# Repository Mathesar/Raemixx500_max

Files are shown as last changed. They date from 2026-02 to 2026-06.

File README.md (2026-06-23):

# Rämixx500_MAX

Rämixx500_MAX is an enhanced version of Sukkoperra's [Rämixx500](https://github.com/SukkoPera/Raemixx500), an Open Hardware remake of the Commodore Amiga 500+ mainboard, revision 8A.1.

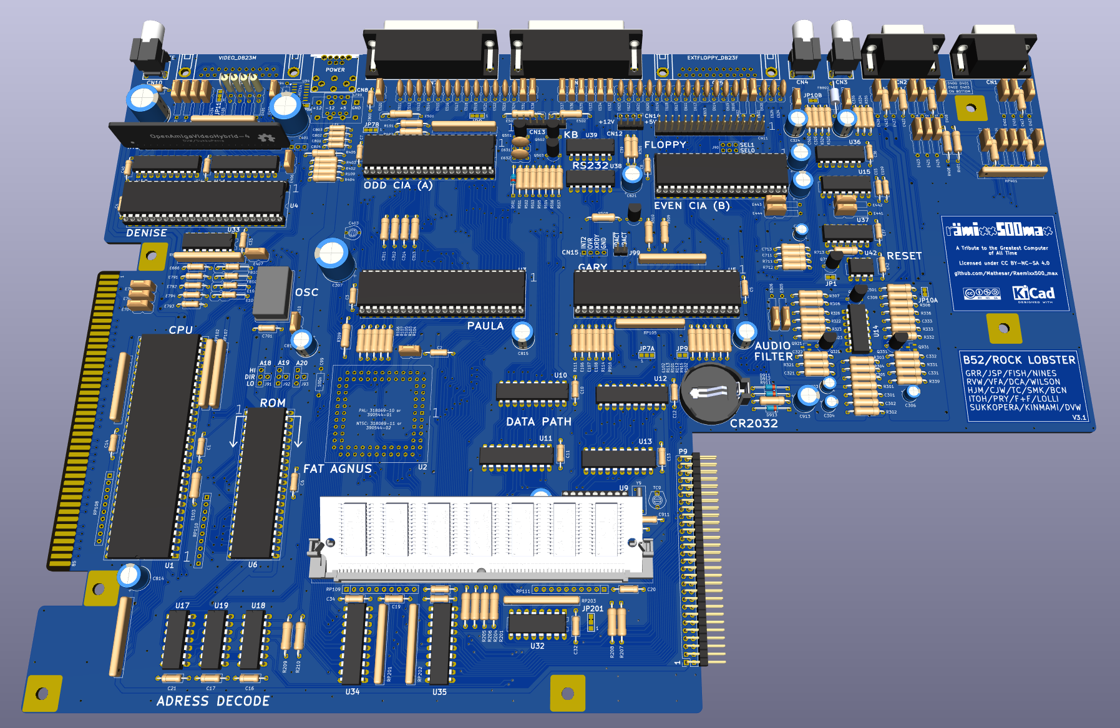
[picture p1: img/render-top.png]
board


## Features
The main feature of the Rämixx500_MAX compared to the original Rämixx500 is more RAM in the form of a 72pins 4Meg SIMM module that gives the Rämixx500_MAX 2Meg CHIP + 1.5Meg SLOW ram. Good working SIMM modules are much easier to source and more reliable than the DIP chips that were originally used in the A500+.

3.5 Megabytes of RAM is the maximum amount an A500+ can use without attaching an accelerator, hence the name Rämixx500_**MAX**.

All the new features of the Rämixx500_MAX are:

* **3.5 Megabytes of RAM**: Using a 72pin SIMM that is at least 4Meg in size.
* **Improved ESD Protection for the Joystick Ports**: The Rämixx500_MAX protects just the lines that go into the sensitive CIA and Paula chips but these lines are more rigorously protected by placing the ESD diodes right at the connectors.
* **Improved Hard Disk LED support**: This version accepts both active high and active low harddisk activity signals. Note that the active low harddisk activity LED input is only compatible with 5V devices. The active high harddisk activity LED input is compatible with both 3.3V and 5V devices.
* **Even more Accurate Dimensions**: The floppy port should fit slightly better. (It already was very, very close in the original Rämixx500 though)
* **Less jumpers**: With the SIMM module, one always has max RAM in all banks, no need to jump around with JP2, JP3 and JP4 anymore.

## Ordering parts and building (important)
Included with the gerbers is a BOM that contains most of the needed parts. Mouser part numbers are also included. 

The BOM and schematics reflect how I built my version. There are some options like buffered sync outputs and extra pullups that I did not use. If one wants these options then they will have to order the additional parts as well. 

Some more remarks regarding how I built my Rämixx500_MAX:

* I did not use sockets for all parts. I only used sockets for the second-hand / rare parts. All the standard logic IC's for example are not socketed. 
* For the 68000 the BOM specifies a high quality "machined" socket. This is done for reliable connection to a socketed accelerator. 
* The other sockets are standard "wiped" sockets. If one is planning to use, for example, an [A500_SD_PLUS](https://github.com/Mathesar/a500-sd-plus-controller) or a RGB2HDMI it is recommended to change the respective sockets (CIA / Denise) to machined sockets as well. This is because I have noticed that modern production wiped sockets get very loose if you insert something other that an IC in them.
* I have populated RP105, RP106 and RP107. This is unlike the original A500+ but these pullups help EPROM compatibility.
* In the BOM I have replaced the MC1488 and MC1489 with the functionally identical SN75C188N and SN75C189N.  
* In the BOM I have replaced the 74F139 with the CD74ACT139E.
* I did not populate the trapdoor connector P9 (not needed anymore).

Like said, the BOM will give you most of the parts needed. The missing parts are:

* **68000** (socket included in BOM)
* **Agnus** (socket included in BOM, only certain versions supported!)
* **Paula** (socket included in BOM)
* **Gary** (socket included in BOM)
* **Denise** (socket included in BOM)
* **2 CIA's** (socket included in BOM)
* **RTC U9** (socket included in BOM)
* **Trimmer capacitor TC-9** (for RTC)
* **Main oscillator X1** (PAL or NTSC)
* **Floppy DSUB connector**
* **Video DSUB connector**
* **Power connector**
* **SIMM module**
* **VIDIOT**

Any SIMM that is 4Meg or larger is supported. EDO and/or parity RAM is also supported.
There is one caveat though when using double-sided SIMM's. As the RTC chip is normally sitting in a socket it might interfere with the memory chips on the bottom of some SIMMs. All double-sided SIMMs I tested fitted but "your mileage may vary".
Also, The SIMM socket sticks out higher than the original DIP RAM chips. This can have implications for some accelerators or other add-ons that sit in the CPU socket. If one plans to use additional add-ons, please review carefully whether these will physically fit on the Rämixx500_MAX. Also see my remarks regarding IC sockets.

For the vidiot, one can use the [OpenAmigaVideoHybrid-04](https://github.com/Mathesar/OpenAmigaVideoHybrid-04) that I have also forked from Sukkoperra.

For further information I highly recommend reading [Sukkopera's wiki here](https://github.com/SukkoPera/Raemixx500/wiki/Assembly-and-Installation). Especially for important information regarding the correct Agnus version.

## Extras
I put my Rämixx500_MAX in a new case from [a1200.net](https://www.a1200.net/). 
For that I also needed a floppy drive so I modded a Sony MFP920 PC drive.
In the [extras](https://github.com/Mathesar/Raemixx500_max/tree/master/extras) folder in this repo one can find the FreeCad and STEP files for an eject button for this drive. I have also created an adapter that converts the Chinon eject button that comes with the a1200.net case to the Sony MFP920 drive. The Chinon eject button itself needs to be trimmed a bit on the back and then glued over the adapter.

## Releases
If one wants to get this board produced, one is recommended to get the latest release rather than the current git version, as the latter might be under development and is not guaranteed to be working.
The latest release also contains the BOM with Mouser part numbers and an interactive HTML BOM which is very helpful when populating the boards.

## Disclaimer
I have personally built and tested V3 of the Rämixx500_MAX. The current release is V3.1 that fixes some (very) minor issues. However, I have not built or tested V3.1 myself. So, build at your own risk.

## License
The Rämixx500_MAX inherits the license of the The Rämixx500 by SukkoPera as quoted below:

> The Rämixx500 documentation, including the design itself, is copyright &copy; SukkoPera 2019-2021 and is licensed under the [Creative Commons Attribution-NonCommercial-ShareAlike 4.0 International License](https://creativecommons.org/licenses/by-nc-sa/4.0/).
> 
> This documentation is distributed *as is* and WITHOUT ANY EXPRESS OR IMPLIED WARRANTIES whatsoever with respect to its functionality, operability or use, including, without limitation, any implied warranties OF MERCHANTABILITY, SATISFACTORY QUALITY, FITNESS FOR A PARTICULAR PURPOSE or infringement. We expressly disclaim any liability whatsoever for any direct, indirect, consequential, incidental or special damages, including, without limitation, lost revenues, lost profits, losses resulting from business interruption or loss of data, regardless of the form of action or legal theory under which the liability may be asserted, even if advised of the possibility or likelihood of such damages.
> 
> This said, I would like this project to progress further. **If anyone would like to do major work on it but is discouraged to do so by the impossibility to exploit the work commercially, please get in touch with me**, I will grant you a private license which will allow you to do that.

## Thanks
- Commodore, for making the coolest machine ever.
- [SukkoPera](https://github.com/SukkoPera) for creating the amazing Rämixx500 and making it open source. Without him this would have never been possible.
- [PeteAU](https://eab.abime.net/member.php?u=58900) for designing an A500 trapdoor RAM expansion and gary adapter. His design inspired me to give the Rämixx500_MAX some additional RAM.

## Pictures

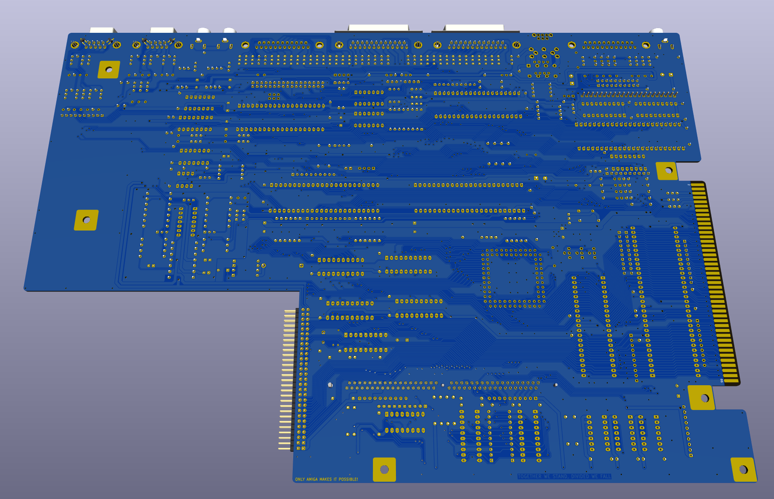
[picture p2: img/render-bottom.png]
bottom render


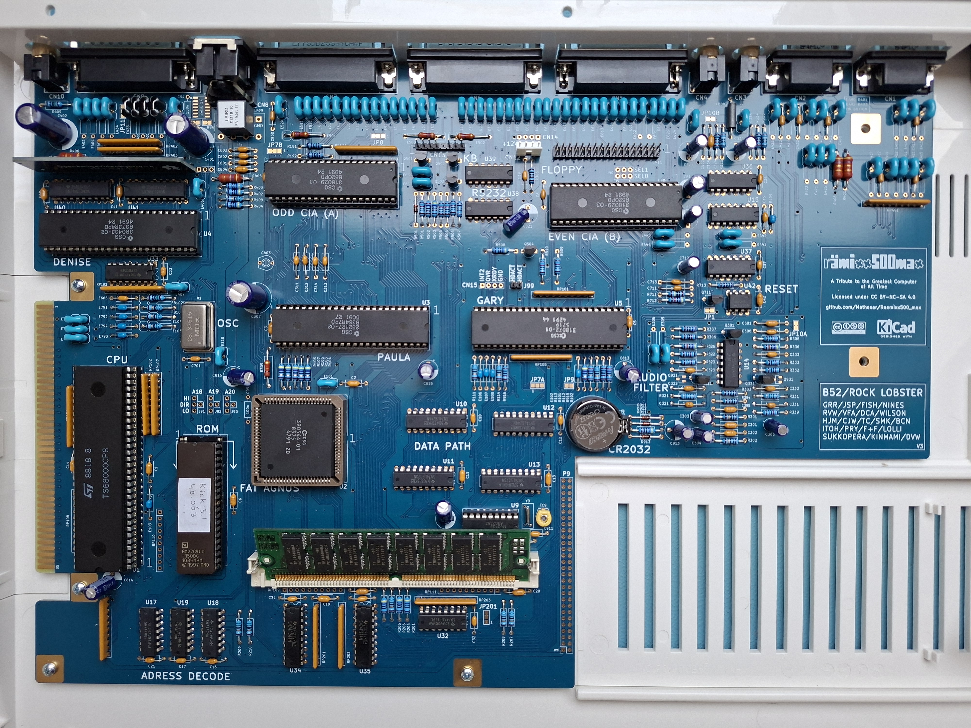
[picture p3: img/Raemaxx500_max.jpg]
Assembled V3 board


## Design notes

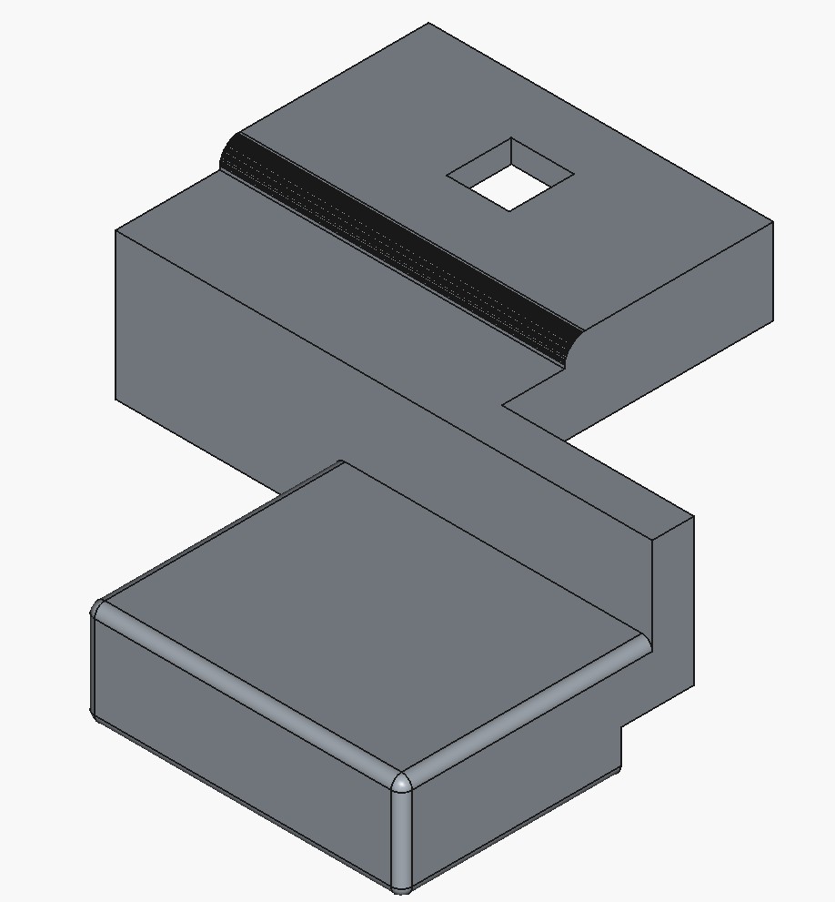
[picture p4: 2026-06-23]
img/MFP920_A500_Eject_Button.jpg

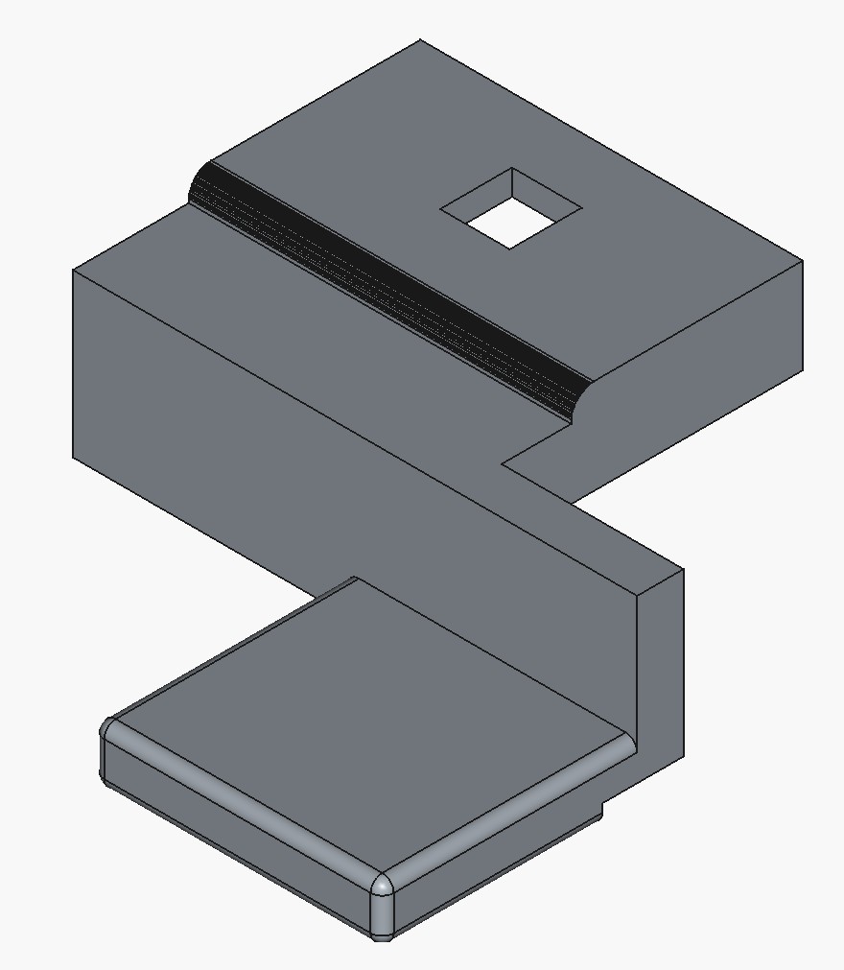
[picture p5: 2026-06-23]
img/MFP920_Chinon_adapter.jpg

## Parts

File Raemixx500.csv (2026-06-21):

Reference | Qty | Value | Footprint | MFG Name | MFG Part Num | Mouser
BT9 | 1 | CR2032 | Raemixx500:Battery_Holder_Coin_2032_BS-7 | EAGLE PLASTIC DEVICES | 122-2420-GR | 122-2420-GR
C1,C2,C3,C4,C5,C6,C9,C11,C13,C14,C18,C19,C20,C40,C41,C42,C804 | 17 | 330n | Raemixx500:C_Axial_L6.3mm_D2.5mm_P10.16mm | KEMET | C440C334K5R5TA7200 | 80-C440C334K5R-TR
C7,C8,C10,C12,C15,C16,C17,C21,C32,C33,C34,C35,C36,C37,C701,C800,C801,C802,C803 | 19 | 10n | Raemixx500:C_Axial_L6.3mm_D2.5mm_P10.16mm | KEMET | C410C103K1R5TA | 80-C410C103K1R
C39,C308,C713 | 3 | 10n | Raemixx500:C_Axial_L9.0mm_D3.2mm_P12.70mm | KEMET | C410C103K1R5TA | 80-C410C103K1R
C301,C302,C305,C325,C335,C501,C502 | 7 | 330n | Raemixx500:C_Axial_L9.0mm_D3.2mm_P12.70mm | KEMET | C440C334K5R5TA7200 | 80-C440C334K5R-TR
C303,C304 | 2 | 22u | Capacitor_THT:CP_Radial_D5.0mm_P2.50mm | PANASONIC | ECA-1EM220I | 667-ECA-1EM220I
C306,C712 | 2 | 10u | Capacitor_THT:CP_Radial_D5.0mm_P2.50mm | PANASONIC | ECA-1EM100I | 667-ECA-1EM100I
C307,C401,C402 | 3 | 1000u | Capacitor_THT:CP_Radial_D12.5mm_P5.00mm | PANASONIC | ECA-1EM102 | 667-ECA-1EM102
C311,C312,C313,C314 | 4 | 47n | Raemixx500:C_Axial_L9.0mm_D3.2mm_P12.70mm | KEMET | C410C473M5R5TA7200 | 80-C410C473M5R-TR
C321,C331,C711 | 3 | 100n | Raemixx500:C_Axial_L9.0mm_D3.2mm_P12.70mm | VISHAY | A104K15X7RF5TAA | 594-A104K15X7RF5TAA
C322,C332 | 2 | 6800p | Raemixx500:C_Axial_L9.0mm_D3.2mm_P12.70mm | KEMET | C410C682K2R5TA7200 | 80-C410C682K2R5TATU
C323,C333 | 2 | 3900p | Raemixx500:C_Axial_L9.0mm_D3.2mm_P12.70mm | KEMET | C410C392K1R5TA | 80-C410C392K1R
C324,C334 | 2 | 22u | Capacitor_THT:CP_Radial_D8.0mm_P5.00mm | PANASONIC | ECA-1EM220B | 667-ECA-1EM220B
C411,C412,C413,C421,C422,C423 | 6 | 1000p | Raemixx500:C_Axial_L9.0mm_D3.2mm_P12.70mm | KEMET | C410C102M5R5TA7200 | 80-C410C102M5R-TR
C811,C812,C813,C814,C815,C816 | 6 | 100u | Capacitor_THT:CP_Radial_D8.0mm_P5.00mm | PANASONIC | ECA-1VM101B | 667-ECA-1VM101B
C821,C822 | 2 | 47u | Capacitor_THT:CP_Radial_D8.0mm_P5.00mm | PANASONIC | ECA-1VM470B | 667-ECA-1VM470B
C911,E666 | 2 | 22p | Raemixx500:C_Axial_L6.3mm_D2.5mm_P10.16mm | KEMET | C410C220J1G5TA | 80-C410C220J1G
C913 | 1 | 4.7u | Capacitor_THT:CP_Radial_D8.0mm_P5.00mm | PANASONIC | ECA-2AM4R7B | 667-ECA-2AM4R7B
CN1 | 1 | LEFT_JOY | Raemixx500:DB_9M | AMPHENOL | L17HTNEP4F1C | 523-L17HTNEP4F1C
CN2 | 1 | RIGHT_JOY | Raemixx500:DB_9M | AMPHENOL | L17HTNEP4F1C | 523-L17HTNEP4F1C
CN3 | 1 | RIGHT | Raemixx500:SWITCHCRAFT_PJRAN1X1U01X | SWITCHCRAFT | PJRAN1X1U01AUX | 502-PJRAN1X1U01AUX
CN4 | 1 | LEFT | Raemixx500:SWITCHCRAFT_PJRAN1X1U01X | SWITCHCRAFT | PJRAN1X1U01AUX | 502-PJRAN1X1U01AUX
CN5 | 1 | EXTFLOPPY_DB23F | Raemixx500:DB_23F | COMMODORE | 390241-03
CN6 | 1 | SERIAL_DB25M | Raemixx500:DB_25M | AMPHENOL | L717SDB25PA4CH4F | 523-L717SDB25PA4CH4F
CN7 | 1 | PARALLEL_DB25F | Raemixx500:DB_25F | AMPHENOL | L77SDB25SA4CH4F | 523-L77SDB25SA4CH4F
CN8 | 1 | POWER | Raemixx500:DS215+DIN8_COMBO | COMMODORE | 252167-01
CN9 | 1 | VIDEO_DB23M | Raemixx500:DB_23M | COMMODORE | 390242-03
CN10 | 1 | COMPOSITE | Raemixx500:SWITCHCRAFT_PJRAN1X1U01X | SWITCHCRAFT | PJRAN1X1U01AUX | 502-PJRAN1X1U01AUX
CN11 | 1 | INTERNAL_FLOPPY | Connector_PinHeader_2.54mm:PinHeader_2x17_P2.54mm_Vertical | AMPHENOL | 77313-101-34LF | 649-77313-101-34LF
CN12 | 1 | FLOPPY_POWER | Connector_PinHeader_2.54mm:PinHeader_1x04_P2.54mm_Vertical | TE CONNECTIVITY | 171825-4 | 571-1718254
CN13 | 1 | KEYBOARD | Raemixx500:Keyboard_Connector | AMPHENOL | 10129378-908003BLF | 649-1012937890803BLF
D400,D401,D402,D403 | 4 | SM05 | Raemixx500:SOT-23_Handsoldering_NoSilk | DIODES INC | SM05-7 | 621-SM05-7
D501,D911,D912,D913 | 4 | 1N4148 | Diode_THT:D_DO-35_SOD27_P12.70mm_Horizontal | ONSEMI | 1N4148TR | 512-1N4148TR
E101,E110,E406,E407,E702,E703,E704 | 7 | 10n | Raemixx500:EMI_Filter_Short | MURATA | DSS1NB32A103Q91A | 81-DSS1NB32A103Q91A
E102,E103,E106,E107,E108 | 5 | 47p | Raemixx500:C_Axial_L9.0mm_D3.2mm_P12.70mm | VISHAY | A470J15C0GF5TAA | 594-A470J15C0GF5TAA
E104,E105,FB101 | 3 | 68 | Raemixx500:EMI_Filter_Long | YAGEO | MFR-25FBF52-68R | 603-MFR-25FBF52-68R
E109,E791,E792,E793,E794 | 5 | 47p | Raemixx500:C_Axial_L6.3mm_D2.5mm_P10.16mm | VISHAY | A470J15C0GF5TAA | 594-A470J15C0GF5TAA
E302,E303 | 2 | 6800p | Raemixx500:EMI_Filter_Short | MURATA | DSS1NB32A682Q91A | 81-DSS1NB32A682Q91A
E305,E306 | 2 | 270p | Raemixx500:EMI_Filter_Long | MURATA | DSS1NB32A271Q91A | 81-DSS1NB32A271Q91A
E401,E403,E404,E405,E408,E601,E602 | 7 | 10n | Raemixx500:EMI_Filter_Long | MURATA | DSS1NB32A103Q91A | 81-DSS1NB32A103Q91A
E402,E434 | 2 | 150p | Raemixx500:EMI_Filter_Long | MURATA | DSS1NB32A151Q91A | 81-DSS1NB32A151Q91A
E411,E412,E413,E414,E421,E422,E423,E424 | 8 | 6800p | Raemixx500:EMI_Filter_Long | MURATA | DSS1NB32A682Q91A | 81-DSS1NB32A682Q91A
E415,E416,E417,E425,E426,E427,E441,E442,E443,E444 | 10 | 470p | Raemixx500:EMI_Filter_Long | MURATA | DSS1NB32A471Q91A | 81-DSS1NB32A471Q91A
E431,E432,E433,E435 | 4 | FERR | Raemixx500:EMI_Filter_Long | ABRACON | ALFB-02 | 815-ALFB-02
E501,E502,E503 | 3 | 47 1/2W | Raemixx500:EMI_Filter_Longer | VISHAY | PR01000104709JA500 | 594-PR01000104709JA5
E511,E512,E513,E514,E515,E516,E517,E518,E519,E521,E522,E523,E524,E611,E612,E613,E614,E615,E616,E617,E618,E619,E620,E621,E622,E623,E624,E625,E626,E631,E632 | 31 | 100p | Raemixx500:EMI_Filter_Short | MURATA | DSS1NB32A101Q91A | 81-DSS1NB32A101Q91A
E520,E531,E533,E535,E536,E537,E538 | 7 | 470p | Raemixx500:EMI_Filter_Short | MURATA | DSS1NB32A471Q91A | 81-DSS1NB32A471Q91A
E532,E534 | 2 | 150p | Raemixx500:EMI_Filter_Short | MURATA | DSS1NB32A151Q91A | 81-DSS1NB32A151Q91A
FB102 | 1 | 150 | Raemixx500:EMI_Filter_Long | YAGEO | MFR-25FBF52-150R | 603-MFR-25FBF52-150R
FB802 | 1 | Ferrite_Bead_Small | Raemixx500:Ferrite_Axial_L9.0mm_D3.2mm_P12.70mm | FAIR-RITE | 2743007111 | 623-2743007111
HY1 | 1 | VIDIOT | Connector_PinHeader_2.54mm:PinHeader_1x22_P2.54mm_Vertical | DVW/SUKKOPERA | OpenAmigaVideoHybrid-04
J99 | 1 | HD_ACT | Connector_PinHeader_2.54mm:PinHeader_1x02_P2.54mm_Vertical | AMPHENOL | 10129378-902003BLF | 649-1012937890203BLF
LF99 | 1 | CM4545Z131B-10 | Raemixx500:CM4545Z131B-10 | LAIRD | CM4545Z131B-10 | 875-CM4545Z131B-10
P9 | 1 | TRAPDOOR | Raemixx500:Trapdoor | ADAM TECH | PH2RA-80-UA | 737-PH2RA-80-UA
Q301,Q502,Q503 | 3 | 2N3906 | Package_TO_SOT_THT:TO-92L_Inline_Wide | ONSEMI | 2N3906BU | 512-2N3906BU
Q321,Q331 | 2 | MPF102 / J113 | Package_TO_SOT_THT:TO-92L_Inline_Wide | ONSEMI | J113 | 512-J113
Q501,Q504,Q711 | 3 | 2N3904 | Package_TO_SOT_THT:TO-92L_Inline_Wide | ONSEMI | 2N3904BU | 512-2N3904BU
R101,R102 | 2 | 27 | Raemixx500:R_Axial_DIN0309_L9.0mm_D3.2mm_P12.70mm_Horizontal | YAGEO | MFR-25FBF52-27R | 603-MFR-25FBF52-27R
R103,R104,R105,R106,R107,R113 | 6 | 47 | Raemixx500:R_Axial_DIN0309_L9.0mm_D3.2mm_P12.70mm_Horizontal | YAGEO | MFR-25FBF52-47R | 603-MFR-25FBF52-47R
R109,R111,R112,R114,R206,R207,R208,R209,R210 | 9 | 68 | Raemixx500:R_Axial_DIN0309_L9.0mm_D3.2mm_P12.70mm_Horizontal | YAGEO | MFR-25FBF52-68R | 603-MFR-25FBF52-68R
R191,R192,R303,R304,R305,R324,R334,R713,R915,R916 | 10 | 1k | Raemixx500:R_Axial_DIN0309_L9.0mm_D3.2mm_P12.70mm_Horizontal | YAGEO | MFR-25FBF52-1K | 603-MFR-25FBF52-1K
R201,R204,R205,R402,R403,R404,R503,R508 | 8 | 4.7k | Raemixx500:R_Axial_DIN0309_L9.0mm_D3.2mm_P12.70mm_Horizontal | YAGEO | MFR-25FBF52-4K7 | 603-MFR-25FBF52-4K7
R301,R302 | 2 | 10 | Raemixx500:R_Axial_DIN0309_L9.0mm_D3.2mm_P12.70mm_Horizontal | YAGEO | MFR-25FBF52-10R | 603-MFR-25FBF52-10R
R306,R308,R322,R323,R332,R333,R339,R501,R504,R505,R506,R509,R510,R914 | 14 | 10K | Raemixx500:R_Axial_DIN0309_L9.0mm_D3.2mm_P12.70mm_Horizontal | YAGEO | MFR-25FBF52-10K | 603-MFR-25FBF52-10K
R307,R502 | 2 | 2.7k | Raemixx500:R_Axial_DIN0309_L9.0mm_D3.2mm_P12.70mm_Horizontal | YAGEO | MFR-25FBF52-2K7 | 603-MFR-25FBF52-2K7
R309 | 1 | 1 | Resistor_THT:R_Axial_DIN0309_L9.0mm_D3.2mm_P15.24mm_Horizontal | VISHAY | PR01000101008JA500 | 594-PR01000101008JA5
R321,R331 | 2 | 360 | Raemixx500:R_Axial_DIN0309_L9.0mm_D3.2mm_P12.70mm_Horizontal | YAGEO | MFR-25FRF52-360R | 603-MFR-25FRF52-360R
R325,R335 | 2 | 390 | Raemixx500:R_Axial_DIN0309_L9.0mm_D3.2mm_P12.70mm_Horizontal | YAGEO | MFR-25FBF52-390R | 603-MFR-25FBF52-390R
R326,R336 | 2 | 470k | Raemixx500:R_Axial_DIN0309_L9.0mm_D3.2mm_P12.70mm_Horizontal | YAGEO | MFR-25FBF52-470K | 603-MFR-25FBF52-470K
R401,R406,R408 | 3 | 4.7 | Resistor_THT:R_Axial_DIN0309_L9.0mm_D3.2mm_P15.24mm_Horizontal | VISHAY | PR01000104708JA500 | 594-PR01000104708JA5
R405 | 1 | 0.47 | Resistor_THT:R_Axial_DIN0309_L9.0mm_D3.2mm_P15.24mm_Horizontal | VISHAY | PR01000104707JA500 | 594-PR01000104707JA5
R409 | 1 | 150 | Resistor_THT:R_Axial_DIN0309_L9.0mm_D3.2mm_P12.70mm_Horizontal | YAGEO | MFR-25FBF52-150R | 603-MFR-25FBF52-150R
R507 | 1 | 100 | Raemixx500:R_Axial_DIN0309_L9.0mm_D3.2mm_P12.70mm_Horizontal | YAGEO | MFR-25FBF52-100R | 603-MFR-25FBF52-100R
R711 | 1 | 1M | Raemixx500:R_Axial_DIN0309_L9.0mm_D3.2mm_P12.70mm_Horizontal | YAGEO | MFR-25FBF52-1M | 603-MFR-25FBF52-1M
R712 | 1 | 47k | Raemixx500:R_Axial_DIN0309_L9.0mm_D3.2mm_P12.70mm_Horizontal | YAGEO | MFR-25FBF52-47K | 603-MFR-25FBF52-47K
R911 | 1 | 470 | Raemixx500:R_Axial_DIN0309_L9.0mm_D3.2mm_P12.70mm_Horizontal | YAGEO | MFR-25FBF52-470R | 603-MFR-25FBF52-470R
RP101,RP102,RP105,RP106,RP107,RP401 | 6 | 4.7k | Resistor_THT:R_Array_SIP10 | BOURNS | 4610X-101-472LF | 652-4610X-1LF-4.7K
RP103 | 1 | 39 | Resistor_THT:R_Array_SIP10 | BOURNS | 4610X-102-390LF | 652-4610X-2LF-39
RP104 | 1 | 470 | Resistor_THT:R_Array_SIP10 | BOURNS | 4610X-101-471LF | 652-4610X-1LF-470
RP201,RP202,RP203 | 3 | 68 | Resistor_THT:R_Array_SIP10 | BOURNS | 4610X-102-680LF | 652-4610X-2LF-68
RP402,RP403 | 2 | 47 | Resistor_THT:R_Array_SIP10 | BOURNS | 4610X-102-470LF | 652-4610X-2LF-47
RP501 | 1 | 10K | Resistor_THT:R_Array_SIP10 | BOURNS | 4610X-101-103LF | 652-4610X-1LF-10K
TC9 | 1 | 12pF - 40pF | Raemixx500:VariCap |  | JML06-1 / 40PF / YELLOW
U1 | 1 | 68000D | Package_DIP:DIP-64_W22.86mm_Socket_LongPads | MILL-MAX | 110-93-964-41-001000 | 575-193964
U2 | 1 | FAT_AGNUS_8375 | Package_LCC:PLCC-84_THT-Socket | MILL-MAX | 940-44-084-24-000000 | 575-948424
U3 | 1 | PAULA | Package_DIP:DIP-48_W15.24mm_Socket_LongPads | 3M | 4848-6000-CP | 517-4848-6000-CP
U4 | 1 | DENISE | Package_DIP:DIP-48_W15.24mm_Socket_LongPads | 3M | 4848-6000-CP | 517-4848-6000-CP
U5 | 1 | GARY_5719 | Package_DIP:DIP-48_W15.24mm_Socket_LongPads | 3M | 4848-6000-CP | 517-4848-6000-CP
U6 | 1 | ROM | Package_DIP:DIP-42_W15.24mm_Socket_LongPads | 3M | 4842-6000-CP | 517-4842-6000-CP
U7,U8 | 2 | VIA_8520 | Package_DIP:DIP-40_W15.24mm_Socket_LongPads | 3M | 4840-6000-CP | 517-4840-6000-CP
U9 | 1 | MSM6242B | Package_DIP:DIP-18_W7.62mm_Socket_LongPads | 3M | 4818-3000-CP | 517-4818-3000-CP
U10,U12 | 2 | 74LS244 | Package_DIP:DIP-20_W7.62mm_LongPads | TI | SN74LS244N | 595-SN74LS244N
U11,U13 | 2 | 74LS373 | Package_DIP:DIP-20_W7.62mm_LongPads | TI | SN74LS373N | 595-SN74LS373N
U14 | 1 | LF347 | Package_DIP:DIP-14_W7.62mm_LongPads | TI | LF347N | 595-LF347N
U15 | 1 | 74LS157 | Package_DIP:DIP-16_W7.62mm_LongPads | TI | SN74LS157N | 595-SN74LS157N
U16 | 1 | SIMM | Raemixx500:SIMM_TE_Connectivity_5822134-3 | TE CONNECTIVITY | 5822134-3 | 571-5822134-3
U17 | 1 | 74F08 | Package_DIP:DIP-14_W7.62mm_LongPads | TI | SN74F08N | 595-SN74F08N
U18 | 1 | 74F74 | Package_DIP:DIP-14_W7.62mm_LongPads | TI | SN74F74N | 595-SN74F74N
U19 | 1 | 74F00 | Package_DIP:DIP-14_W7.62mm_LongPads | TI | SN74F00N | 595-SN74F00N
U32 | 1 | 74F139 | Package_DIP:DIP-16_W7.62mm_LongPads | TI | CD74ACT139E | 595-CD74ACT139E
U33 | 1 | 74F258 | Package_DIP:DIP-16_W7.62mm_LongPads | TI | SN74F258N | 595-SN74F258N
U34,U35 | 2 | 74F244 | Package_DIP:DIP-20_W7.62mm_LongPads | TI | SN74F244N | 595-SN74F244N
U36 | 1 | 74LS05 | Package_DIP:DIP-14_W7.62mm_LongPads | TI | SN74LS05N | 595-SN74LS05N
U37 | 1 | 74LS32 | Package_DIP:DIP-14_W7.62mm_LongPads | TI | SN74LS32N | 595-SN74LS32N
U38 | 1 | MC1488 | Package_DIP:DIP-14_W7.62mm_LongPads | TI | SN75C188N | 595-SN75C188N
U39 | 1 | MC1489 | Package_DIP:DIP-14_W7.62mm_LongPads | TI | SN75C189N | 595-SN75C189N
U40,U41 | 2 | 74HCT245 | Package_DIP:DIP-20_W7.62mm_LongPads | TI | SN74HCT245N | 595-SN74HCT245N
U42 | 1 | NE555 | Package_DIP:DIP-8_W7.62mm_LongPads | TI | SA555P | 595-SA555P
X1 | 1 | XTAL | Oscillator:Oscillator_DIP-14
Y9 | 1 | 32.768kHz | Raemixx500:Crystal_RTC | ECS | ECS-.327-12.5-13X | 520-TFC2X6-X

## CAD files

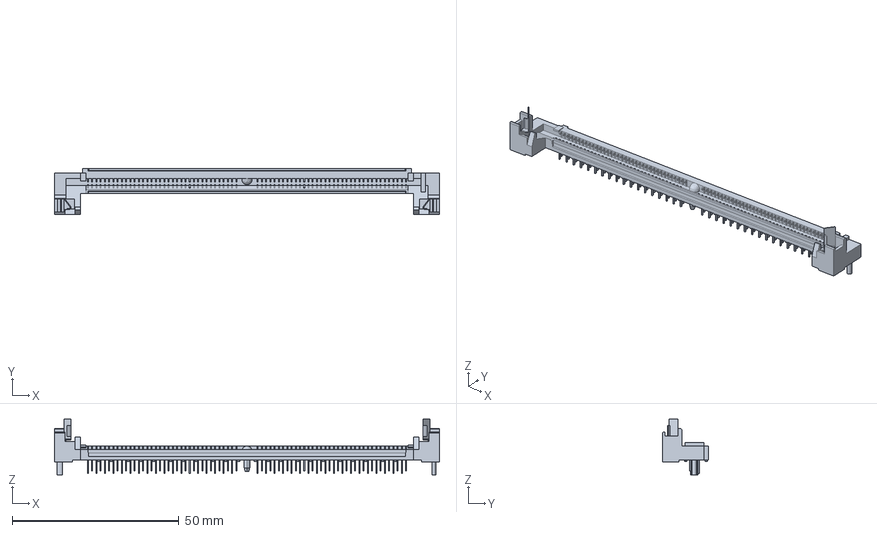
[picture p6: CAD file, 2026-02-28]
3dModels/c-5822134-3-b-3d.stp
115.3 x 13.7 x 16.8 mm

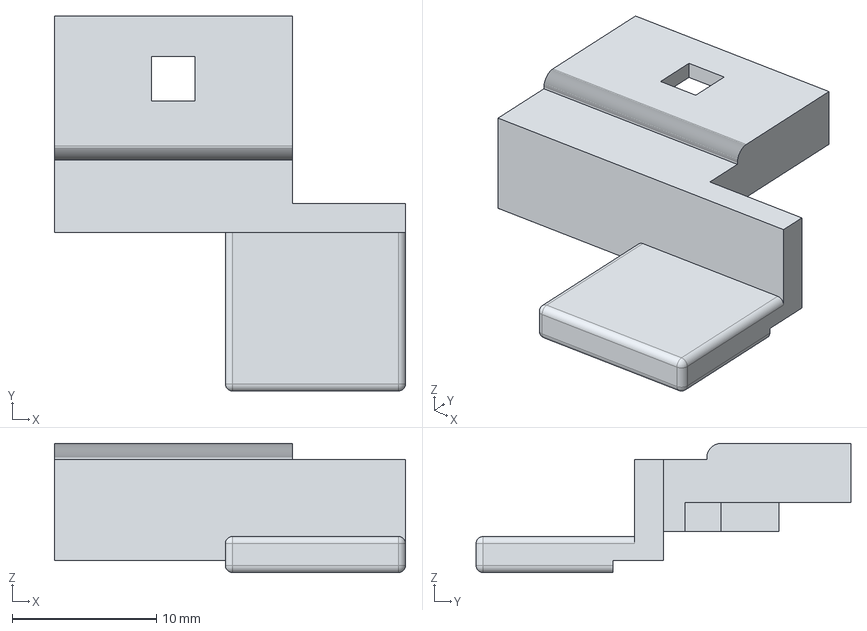
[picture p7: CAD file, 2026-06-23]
extras/eject_button_mfp920_to_chinon_button.step
24.4 x 26.0 x 8.95 mm

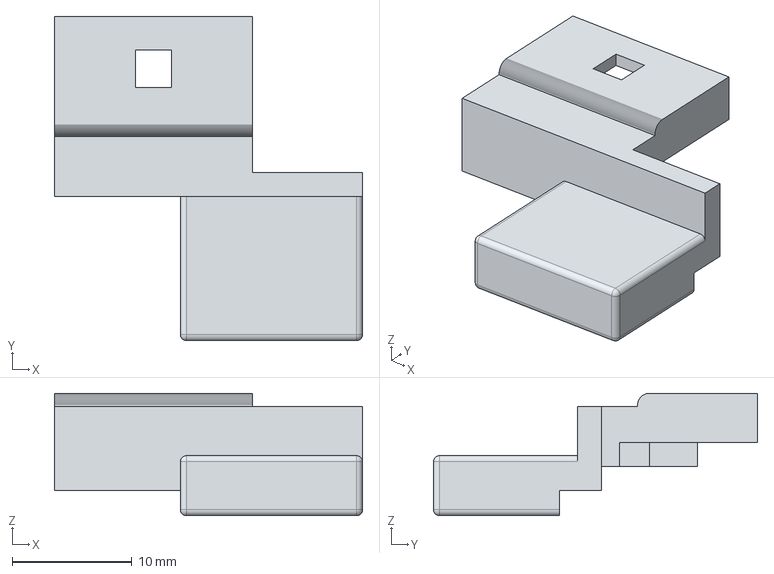
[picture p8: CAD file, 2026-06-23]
extras/eject_button_mfp920_A500.step
25.7 x 27.0 x 10.2 mm

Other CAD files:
extras/eject_button_mfp920_A500.FCStd
extras/eject_button_mfp920_to_chinon_button.FCStd

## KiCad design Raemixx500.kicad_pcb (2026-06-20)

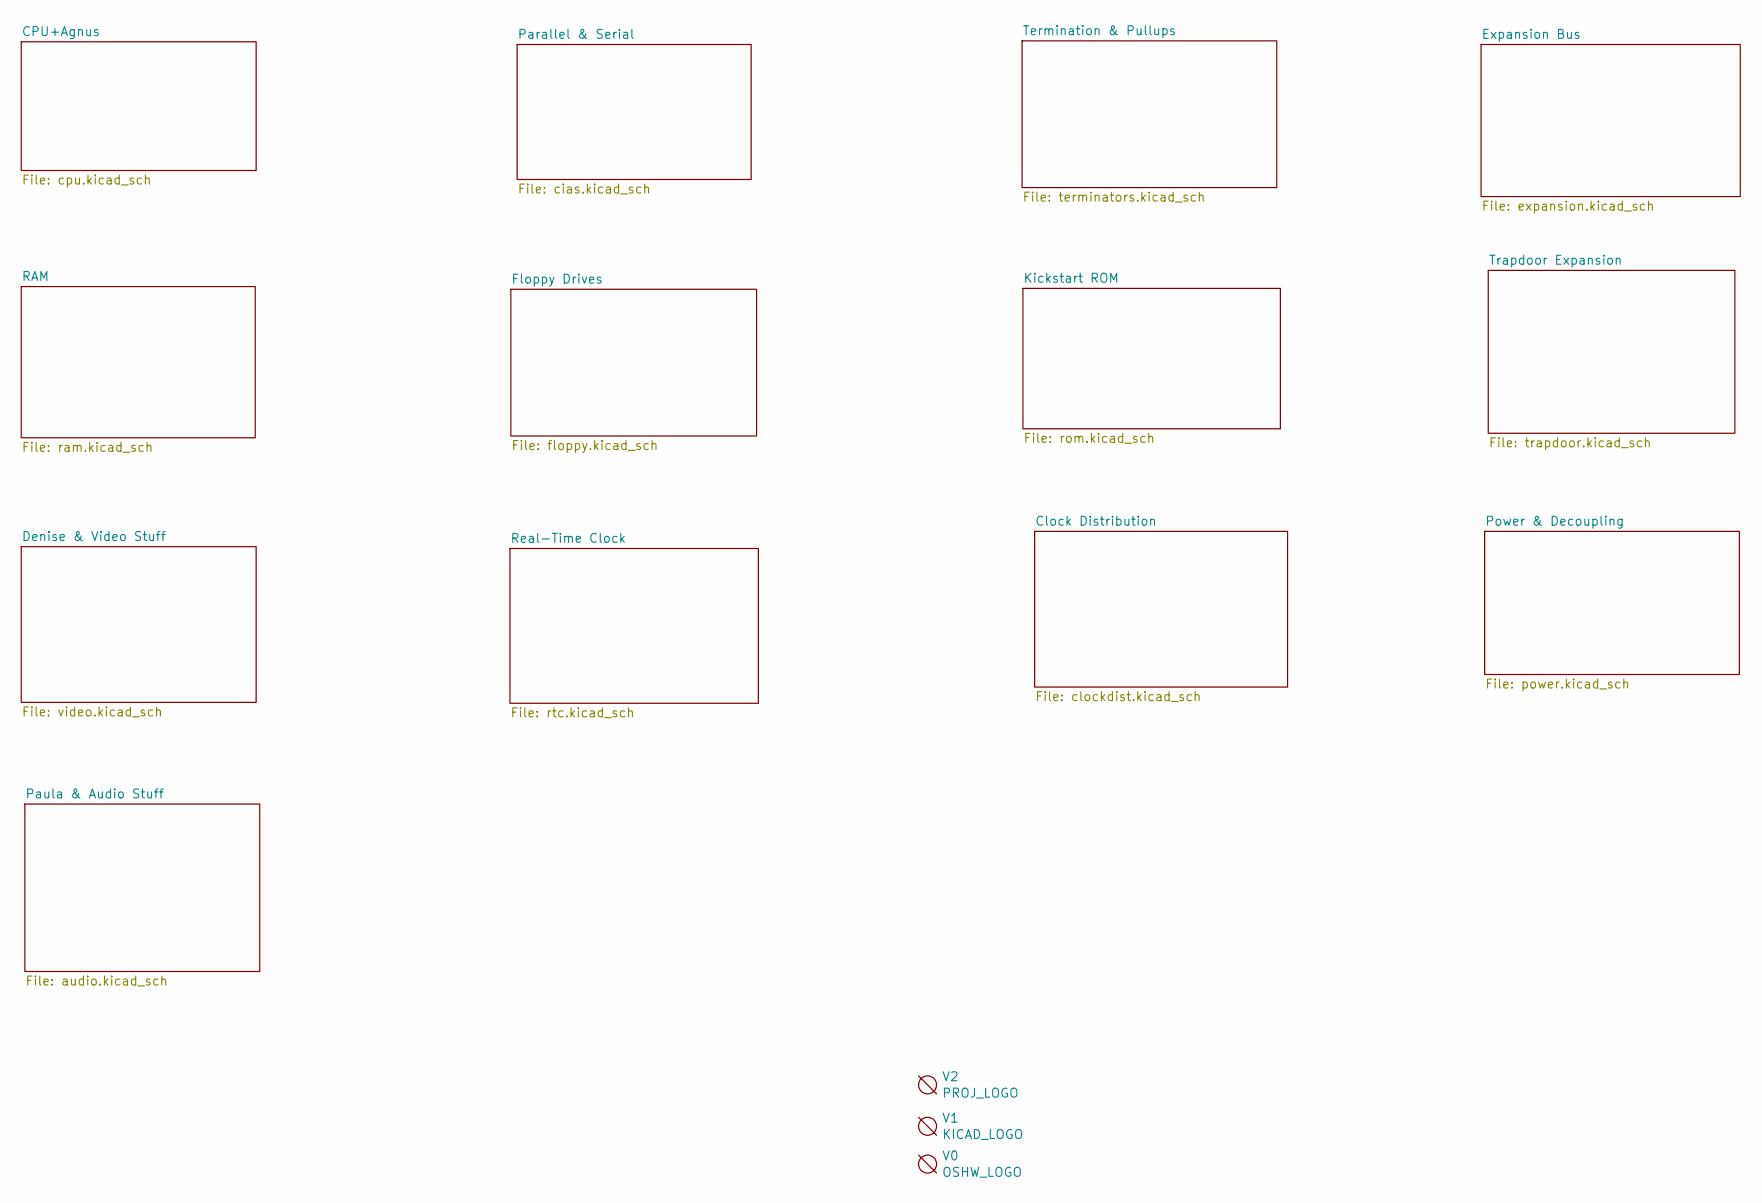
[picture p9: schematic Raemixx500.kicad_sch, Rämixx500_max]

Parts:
V0: OSHW_LOGO; cc_by_nc_sa; MFG Part Num SKIP
V1: KICAD_LOGO; KiCad-Logo2_6mm_SilkScreen; MFG Part Num SKIP
V2: PROJ_LOGO; logo_max; MFG Part Num SKIP

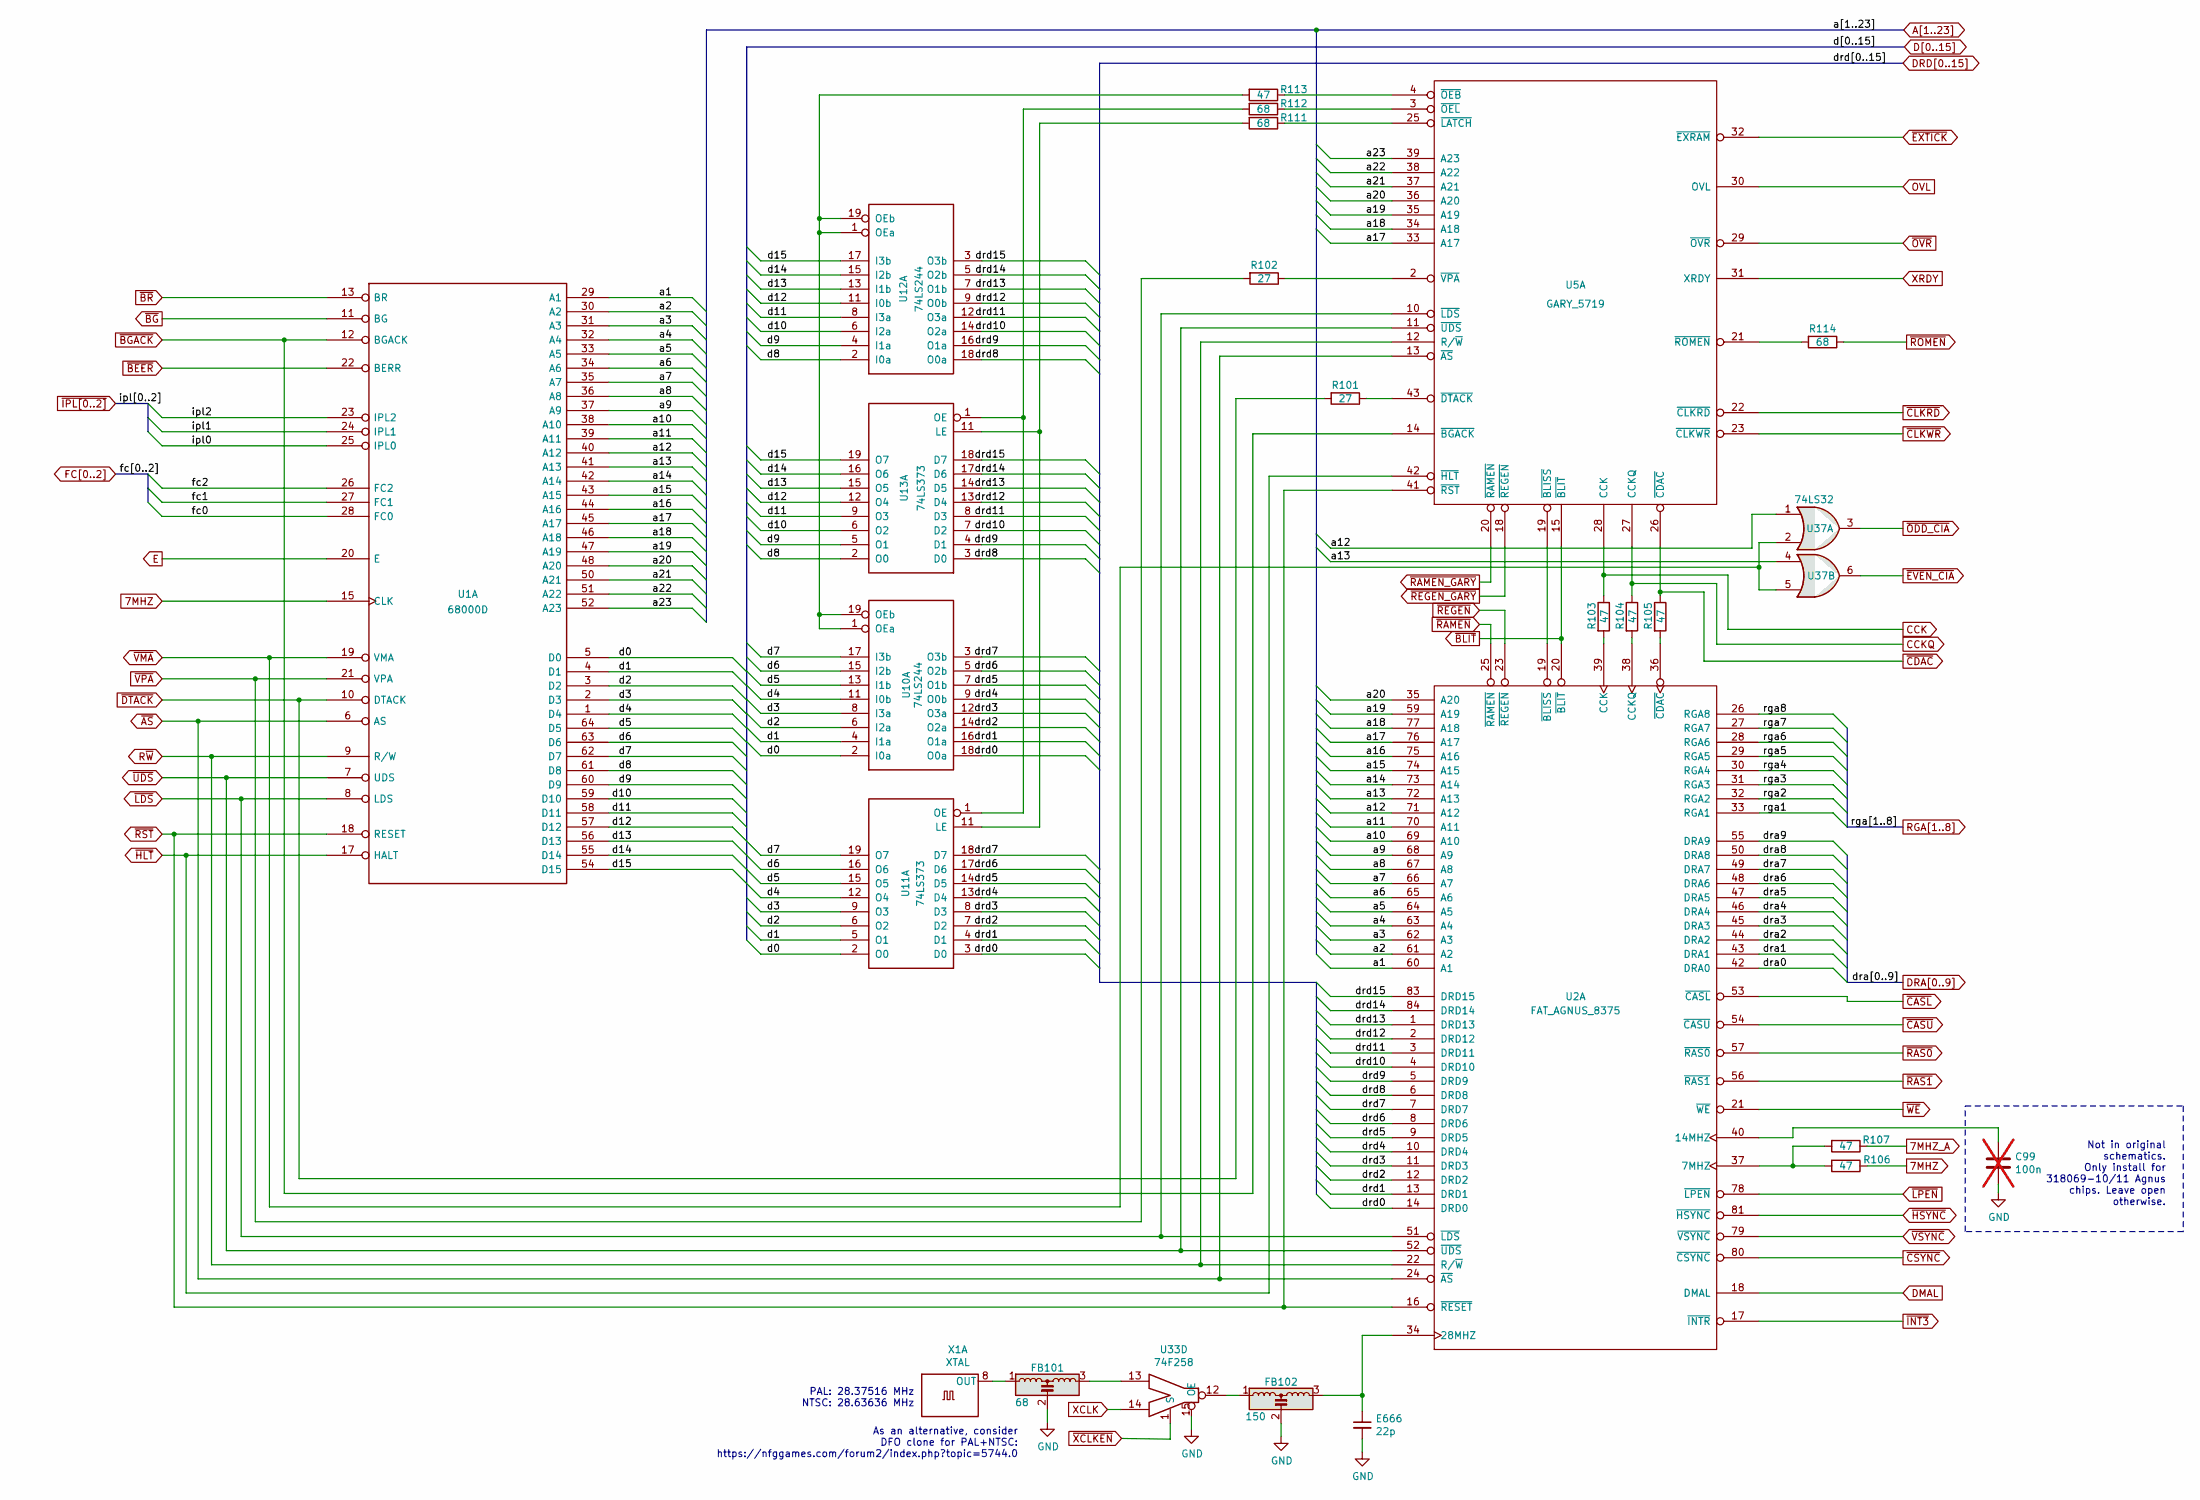
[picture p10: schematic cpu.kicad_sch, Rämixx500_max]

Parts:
C99: 100n; C_Axial_L6.3mm_D2.5mm_P10.16mm; MFG Part Num A104K15X7RF5TAA; Mouser 594-A104K15X7RF5TAA; not fitted
E666: 22p; C_Axial_L6.3mm_D2.5mm_P10.16mm; MFG Part Num C410C220J1G5TA; Mouser 80-C410C220J1G
FB101: 68; EMI_Filter_Long; MFG Part Num MFR-25FBF52-68R; Mouser 603-MFR-25FBF52-68R
FB102: 150; EMI_Filter_Long; MFG Part Num MFR-25FBF52-150R; Mouser 603-MFR-25FBF52-150R
R101, R102: 27; R_Axial_DIN0309_L9.0mm_D3.2mm_P12.70mm_Horizontal; MFG Part Num MFR-25FBF52-27R; Mouser 603-MFR-25FBF52-27R
R103, R104, R105, R106, R107, R113: 47; R_Axial_DIN0309_L9.0mm_D3.2mm_P12.70mm_Horizontal; MFG Part Num MFR-25FBF52-47R; Mouser 603-MFR-25FBF52-47R
R111, R112, R114: 68; R_Axial_DIN0309_L9.0mm_D3.2mm_P12.70mm_Horizontal; MFG Part Num MFR-25FBF52-68R; Mouser 603-MFR-25FBF52-68R
U1: 68000D; DIP-64_W22.86mm_Socket_LongPads; MFG Part Num 110-93-964-41-001000; Mouser 575-193964
U2: FAT_AGNUS_8375; PLCC-84_THT-Socket; MFG Part Num 940-44-084-24-000000; Mouser 575-948424
U5: GARY_5719; DIP-48_W15.24mm_Socket_LongPads; MFG Part Num 4848-6000-CP; Mouser 517-4848-6000-CP
U10, U12: 74LS244; DIP-20_W7.62mm_LongPads; MFG Part Num SN74LS244N; Mouser 595-SN74LS244N
U11, U13: 74LS373; DIP-20_W7.62mm_LongPads; MFG Part Num SN74LS373N; Mouser 595-SN74LS373N
U33: 74F258; DIP-16_W7.62mm_LongPads; MFG Part Num SN74F258N; Mouser 595-SN74F258N
U37: 74LS32; DIP-14_W7.62mm_LongPads; MFG Part Num SN74LS32N; Mouser 595-SN74LS32N
X1: XTAL; Oscillator_DIP-14

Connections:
7MHZ: R106.1, U1.15 (CLK); also elsewhere on the board
7MHZ_A: R107.1; also elsewhere on the board
A1: U1.29 (A1), U2.60 (A1); also elsewhere on the board
A2: U1.30 (A2), U2.61 (A2); also elsewhere on the board
A3: U1.31 (A3), U2.62 (A3); also elsewhere on the board
A4: U1.32 (A4), U2.63 (A4); also elsewhere on the board
A5: U1.33 (A5), U2.64 (A5); also elsewhere on the board
A6: U1.34 (A6), U2.65 (A6); also elsewhere on the board
A7: U1.35 (A7), U2.66 (A7); also elsewhere on the board
A8: U1.36 (A8), U2.67 (A8); also elsewhere on the board
A9: U1.37 (A9), U2.68 (A9); also elsewhere on the board
A10: U1.38 (A10), U2.69 (A10); also elsewhere on the board
A11: U1.39 (A11), U2.70 (A11); also elsewhere on the board
A12: U1.40 (A12), U2.71 (A12), U37.1; also elsewhere on the board
A13: U1.41 (A13), U2.72 (A13), U37.4; also elsewhere on the board
A14: U1.42 (A14), U2.73 (A14); also elsewhere on the board
A15: U1.43 (A15), U2.74 (A15); also elsewhere on the board
A16: U1.44 (A16), U2.75 (A16); also elsewhere on the board
A17: U1.45 (A17), U2.76 (A17), U5.33 (A17); also elsewhere on the board
A18: U1.46 (A18), U2.77 (A18), U5.34 (A18); also elsewhere on the board
A19: U1.47 (A19), U2.59 (A19), U5.35 (A19); also elsewhere on the board
A20: U1.48 (A20), U2.35 (A20), U5.36 (A20); also elsewhere on the board
A21: U1.50 (A21), U5.37 (A21); also elsewhere on the board
A22: U1.51 (A22), U5.38 (A22); also elsewhere on the board
A23: U1.52 (A23), U5.39 (A23); also elsewhere on the board
CCK: R103.1, U5.28 (CCK); also elsewhere on the board
CCKQ: R104.1, U5.27 (CCKQ); also elsewhere on the board
D0: U1.5 (D0), U10.2 (I0a), U11.2 (O0); also elsewhere on the board
D1: U1.4 (D1), U10.4 (I1a), U11.5 (O1); also elsewhere on the board
D2: U1.3 (D2), U10.6 (I2a), U11.6 (O2); also elsewhere on the board
D3: U1.2 (D3), U10.8 (I3a), U11.9 (O3); also elsewhere on the board
D4: U1.1 (D4), U10.11 (I0b), U11.12 (O4); also elsewhere on the board
D5: U1.64 (D5), U10.13 (I1b), U11.15 (O5); also elsewhere on the board
D6: U1.63 (D6), U10.15 (I2b), U11.16 (O6); also elsewhere on the board
D7: U1.62 (D7), U10.17 (I3b), U11.19 (O7); also elsewhere on the board
D8: U1.61 (D8), U12.2 (I0a), U13.2 (O0); also elsewhere on the board
D9: U1.60 (D9), U12.4 (I1a), U13.5 (O1); also elsewhere on the board
D10: U1.59 (D10), U12.6 (I2a), U13.6 (O2); also elsewhere on the board
D11: U1.58 (D11), U12.8 (I3a), U13.9 (O3); also elsewhere on the board
D12: U1.57 (D12), U12.11 (I0b), U13.12 (O4); also elsewhere on the board
D13: U1.56 (D13), U12.13 (I1b), U13.15 (O5); also elsewhere on the board
D14: U1.55 (D14), U12.15 (I2b), U13.16 (O6); also elsewhere on the board
D15: U1.54 (D15), U12.17 (I3b), U13.19 (O7); also elsewhere on the board
DMAL: U2.18 (DMAL); also elsewhere on the board
DRA0: U2.42 (DRA0); also elsewhere on the board
DRA1: U2.43 (DRA1); also elsewhere on the board
DRA2: U2.44 (DRA2); also elsewhere on the board
DRA3: U2.45 (DRA3); also elsewhere on the board
DRA4: U2.46 (DRA4); also elsewhere on the board
DRA5: U2.47 (DRA5); also elsewhere on the board
DRA6: U2.48 (DRA6); also elsewhere on the board
DRA7: U2.49 (DRA7); also elsewhere on the board
DRA8: U2.50 (DRA8); also elsewhere on the board
DRA9: U2.55 (DRA9); also elsewhere on the board
DRD0: U2.14 (DRD0), U10.18 (O0a), U11.3 (D0); also elsewhere on the board
DRD1: U2.13 (DRD1), U10.16 (O1a), U11.4 (D1); also elsewhere on the board
DRD2: U2.12 (DRD2), U10.14 (O2a), U11.7 (D2); also elsewhere on the board
DRD3: U2.11 (DRD3), U10.12 (O3a), U11.8 (D3); also elsewhere on the board
DRD4: U2.10 (DRD4), U10.9 (O0b), U11.13 (D4); also elsewhere on the board
DRD5: U2.9 (DRD5), U10.7 (O1b), U11.14 (D5); also elsewhere on the board
DRD6: U2.8 (DRD6), U10.5 (O2b), U11.17 (D6); also elsewhere on the board
DRD7: U2.7 (DRD7), U10.3 (O3b), U11.18 (D7); also elsewhere on the board
DRD8: U2.6 (DRD8), U12.18 (O0a), U13.3 (D0); also elsewhere on the board
DRD9: U2.5 (DRD9), U12.16 (O1a), U13.4 (D1); also elsewhere on the board
DRD10: U2.4 (DRD10), U12.14 (O2a), U13.7 (D2); also elsewhere on the board
DRD11: U2.3 (DRD11), U12.12 (O3a), U13.8 (D3); also elsewhere on the board
DRD12: U2.2 (DRD12), U12.9 (O0b), U13.13 (D4); also elsewhere on the board
DRD13: U2.1 (DRD13), U12.7 (O1b), U13.14 (D5); also elsewhere on the board
DRD14: U2.84 (DRD14), U12.5 (O2b), U13.17 (D6); also elsewhere on the board
DRD15: U2.83 (DRD15), U12.3 (O3b), U13.18 (D7); also elsewhere on the board
E: U1.20 (E); also elsewhere on the board
FC0: U1.28 (FC0); also elsewhere on the board
FC1: U1.27 (FC1); also elsewhere on the board
FC2: U1.26 (FC2); also elsewhere on the board
GND: C99.2, E666.2, FB101.2, FB102.2, U33.15 (OE); also elsewhere on the board
unnamed: FB101.3, U33.13
unnamed: FB102.1, U33.12
unnamed: R106.2, R107.2, U2.37 (7MHZ)
unnamed: C99.1, U2.40 (14MHZ)
unnamed: E666.1, FB102.3, U2.34 (28MHZ)
unnamed: R103.2, U2.39 (CCK)
unnamed: R104.2, U2.38 (CCKQ)
unnamed: U2.19 (~BLISS), U5.19 (~BLISS)
unnamed: R105.2, U2.36 (~CDAC)
unnamed: R101.1, U5.43 (~DTACK)
unnamed: R111.1, U5.25 (~LATCH)
unnamed: R113.1, U5.4 (~OEB)
unnamed: R112.1, U5.3 (~OEL)
unnamed: R114.2, U5.21 (~ROMEN)
unnamed: R102.1, U5.2 (~VPA)
unnamed: R113.2, U10.1 (OEa), U10.19 (OEb), U12.1 (OEa), U12.19 (OEb)
unnamed: R111.2, U11.11 (LE), U13.11 (LE)
unnamed: R112.2, U11.1 (OE), U13.1 (OE)
unnamed: FB101.1, X1.8 (OUT)
OVL: U5.30 (OVL); also elsewhere on the board
RGA1: U2.33 (RGA1); also elsewhere on the board
RGA2: U2.32 (RGA2); also elsewhere on the board
RGA3: U2.31 (RGA3); also elsewhere on the board
RGA4: U2.30 (RGA4); also elsewhere on the board
RGA5: U2.29 (RGA5); also elsewhere on the board
RGA6: U2.28 (RGA6); also elsewhere on the board
RGA7: U2.27 (RGA7); also elsewhere on the board
RGA8: U2.26 (RGA8); also elsewhere on the board
R~W: U1.9 (R/W), U2.22 (R/~W), U5.12 (R/~W); also elsewhere on the board
XCLK: U33.14; also elsewhere on the board
XRDY: U5.31 (XRDY); also elsewhere on the board
~AS: U1.6 (AS), U2.24 (~AS), U5.13 (~AS); also elsewhere on the board
~BEER: U1.22 (BERR); also elsewhere on the board
~BGACK: U1.12 (BGACK), U5.14 (~BGACK); also elsewhere on the board
~BG: U1.11 (BG); also elsewhere on the board
~BLIT: U2.20 (~BLIT), U5.15 (~BLIT); also elsewhere on the board
~BR: U1.13 (BR); also elsewhere on the board
~CASL: U2.53 (~CASL); also elsewhere on the board
~CASU: U2.54 (~CASU); also elsewhere on the board
~CDAC: R105.1, U5.26 (~CDAC); also elsewhere on the board
~CLKRD: U5.22 (~CLKRD); also elsewhere on the board
~CLKWR: U5.23 (~CLKWR); also elsewhere on the board
~CSYNC: U2.80 (~CSYNC); also elsewhere on the board
~DTACK: R101.2, U1.10 (DTACK); also elsewhere on the board
~EVEN_CIA: U37.6; also elsewhere on the board
~EXTICK: U5.32 (~EXRAM); also elsewhere on the board
~HLT: U1.17 (HALT), U5.42 (~HLT); also elsewhere on the board
~HSYNC: U2.81 (~HSYNC); also elsewhere on the board
~INT3: U2.17 (~INTR); also elsewhere on the board
~IPL0: U1.25 (IPL0); also elsewhere on the board
~IPL1: U1.24 (IPL1); also elsewhere on the board
~IPL2: U1.23 (IPL2); also elsewhere on the board
~LDS: U1.8 (LDS), U2.51 (~LDS), U5.10 (~LDS); also elsewhere on the board
~LPEN: U2.78 (~LPEN); also elsewhere on the board
~ODD_CIA: U37.3; also elsewhere on the board
~OVR: U5.29 (~OVR); also elsewhere on the board
~RAMEN_GARY: U5.20 (~RAMEN); also elsewhere on the board
~RAMEN: U2.25 (~RAMEN); also elsewhere on the board
~RAS0: U2.57 (~RAS0); also elsewhere on the board
~RAS1: U2.56 (~RAS1); also elsewhere on the board
~REGEN_GARY: U5.18 (~REGEN); also elsewhere on the board
~REGEN: U2.23 (~REGEN); also elsewhere on the board
~ROMEN: R114.1; also elsewhere on the board
~RST: U1.18 (RESET), U2.16 (~RESET), U5.41 (~RST); also elsewhere on the board
~UDS: U1.7 (UDS), U2.52 (~UDS), U5.11 (~UDS); also elsewhere on the board
~VMA: U1.19 (VMA), U37.2, U37.5; also elsewhere on the board
~VPA: R102.2, U1.21 (VPA); also elsewhere on the board
~VSYNC: U2.79 (~VSYNC); also elsewhere on the board
~WE: U2.21 (~WE); also elsewhere on the board
~XCLKEN: U33.1 (S); also elsewhere on the board

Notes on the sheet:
PAL: 28.37516 MHz NTSC: 28.63636 MHz
As an alternative, consider DFO clone for PAL+NTSC: https://nfggames.com/forum2/index.php?topic=5744.0
Not in original schematics. Only install for 318069-10/11 Agnus chips. Leave open otherwise.

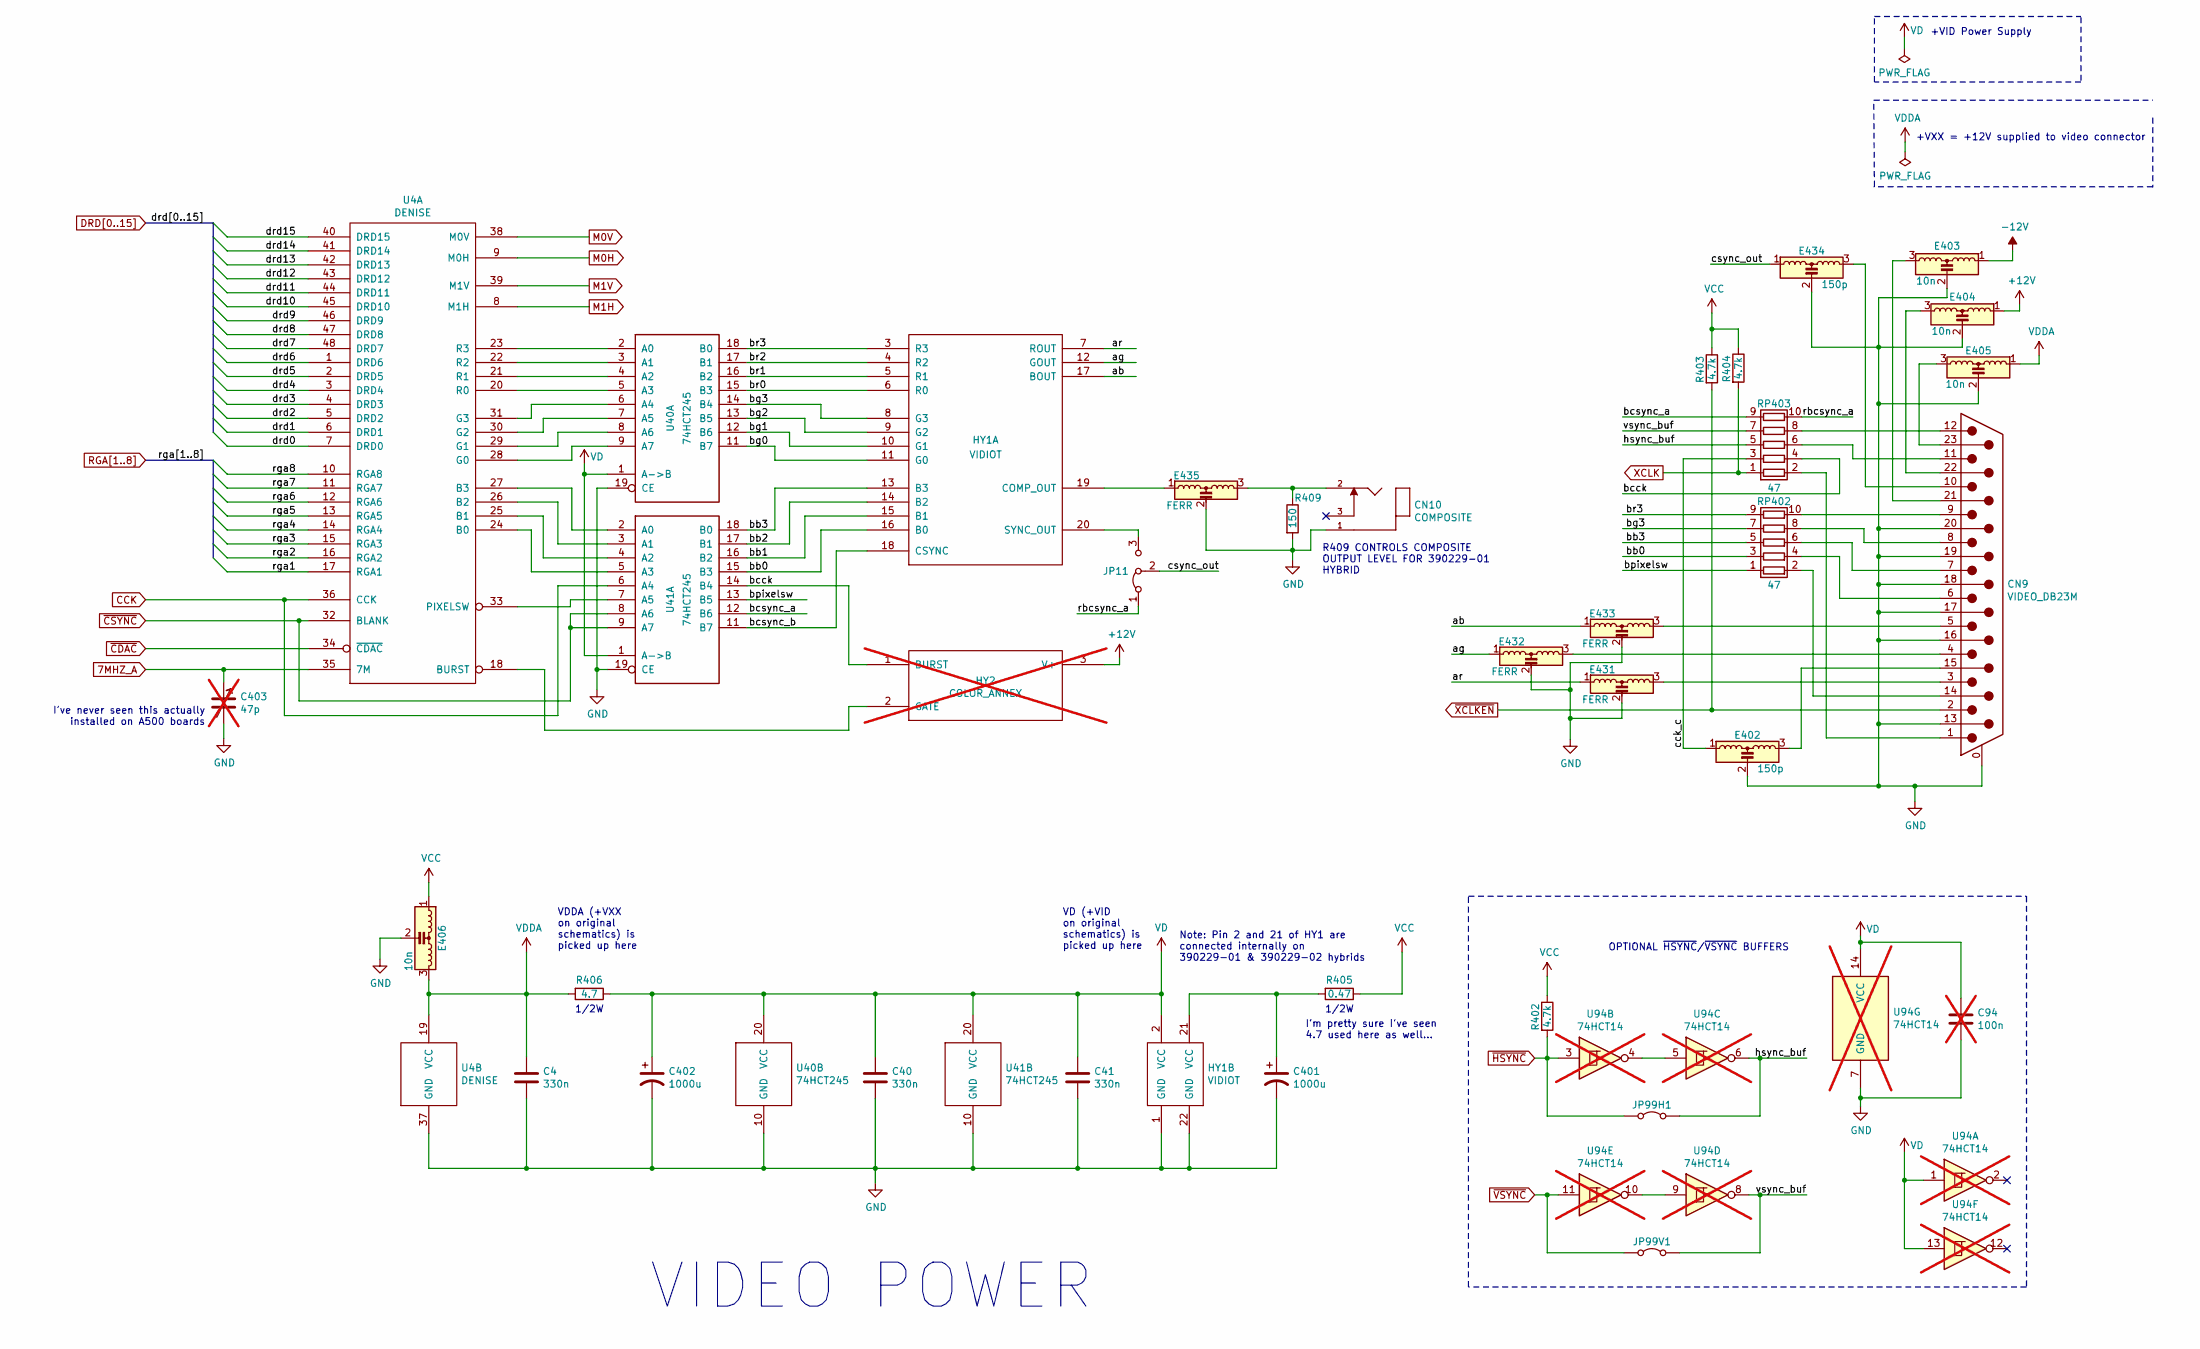
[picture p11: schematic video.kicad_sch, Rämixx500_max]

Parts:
C4, C40, C41: 330n; C_Axial_L6.3mm_D2.5mm_P10.16mm; MFG Part Num C440C334K5R5TA7200; Mouser 80-C440C334K5R-TR
C94: 100n; C_Axial_L6.3mm_D2.5mm_P10.16mm; MFG Part Num A104K15X7RF5TAA; Mouser 594-A104K15X7RF5TAA; not fitted
C401, C402: 1000u; CP_Radial_D12.5mm_P5.00mm; MFG Part Num ECA-1EM102; Mouser 667-ECA-1EM102
C403: 47p; VariCap; MFG Part Num SKIP; not fitted
CN9: VIDEO_DB23M; DB_23M; MFG Part Num 390242-03
CN10: COMPOSITE; SWITCHCRAFT_PJRAN1X1U01X; MFG Part Num PJRAN1X1U01AUX; Mouser 502-PJRAN1X1U01AUX
E402, E434: 150p; EMI_Filter_Long; MFG Part Num DSS1NB32A151Q91A; Mouser 81-DSS1NB32A151Q91A
E403, E404, E405: 10n; EMI_Filter_Long; MFG Part Num DSS1NB32A103Q91A; Mouser 81-DSS1NB32A103Q91A
E406: 10n; EMI_Filter_Short; MFG Part Num DSS1NB32A103Q91A; Mouser 81-DSS1NB32A103Q91A
E431, E432, E433, E435: FERR; EMI_Filter_Long; MFG Part Num ALFB-02; Mouser 815-ALFB-02
HY1: VIDIOT; PinHeader_1x22_P2.54mm_Vertical; MFG Part Num OpenAmigaVideoHybrid-04
HY2: COLOR_ANNEX; PinHeader_1x03_P2.54mm_Vertical; MFG Part Num SKIP; not fitted
JP11: Jumper_3_Bridged12; Jumper3-Bridged12; MFG Part Num SKIP
JP99H1, JP99V1: Jumper_2_Bridged; Jumper2-Bridged; MFG Part Num SKIP
R402, R403, R404: 4.7k; R_Axial_DIN0309_L9.0mm_D3.2mm_P12.70mm_Horizontal; MFG Part Num MFR-25FBF52-4K7; Mouser 603-MFR-25FBF52-4K7
R405: 0.47; R_Axial_DIN0309_L9.0mm_D3.2mm_P15.24mm_Horizontal; MFG Part Num PR01000104707JA500; Mouser 594-PR01000104707JA5
R406: 4.7; R_Axial_DIN0309_L9.0mm_D3.2mm_P15.24mm_Horizontal; MFG Part Num PR01000104708JA500; Mouser 594-PR01000104708JA5
R409: 150; R_Axial_DIN0309_L9.0mm_D3.2mm_P12.70mm_Horizontal; MFG Part Num MFR-25FBF52-150R; Mouser 603-MFR-25FBF52-150R
RP402, RP403: 47; R_Array_SIP10; MFG Part Num 4610X-102-470LF; Mouser 652-4610X-2LF-47
U4: DENISE; DIP-48_W15.24mm_Socket_LongPads; MFG Part Num 4848-6000-CP; Mouser 517-4848-6000-CP
U40, U41: 74HCT245; DIP-20_W7.62mm_LongPads; MFG Part Num SN74HCT245N; Mouser 595-SN74HCT245N
U94: 74HCT14; SOIC-14_3.9x8.7mm_P1.27mm; not fitted

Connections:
7MHZ_A: C403.1, U4.35 (7M); also elsewhere on the board
+12V: E404.1, HY2.3 (V+); also elsewhere on the board
-12V: E403.1; also elsewhere on the board
/Denise & Video Stuff/ab: E433.1, HY1.17 (BOUT)
/Denise & Video Stuff/ag: E432.1, HY1.12 (GOUT)
/Denise & Video Stuff/ar: E431.1, HY1.7 (ROUT)
/Denise & Video Stuff/bb0: HY1.16 (B0), RP402.3 (R2.1), U41.15 (B3)
/Denise & Video Stuff/bb1: HY1.15 (B1), U41.16 (B2)
/Denise & Video Stuff/bb2: HY1.14 (B2), U41.17 (B1)
/Denise & Video Stuff/bb3: HY1.13 (B3), RP402.5 (R3.1), U41.18 (B0)
/Denise & Video Stuff/bcck: HY2.1 (BURST), RP403.4 (R2.2), U41.14 (B4)
/Denise & Video Stuff/bcsync_a: RP403.9 (R5.1), U41.12 (B6)
/Denise & Video Stuff/bcsync_b: HY1.18 (CSYNC), U41.11 (B7)
/Denise & Video Stuff/bg0: HY1.11 (G0), U40.11 (B7)
/Denise & Video Stuff/bg1: HY1.10 (G1), U40.12 (B6)
/Denise & Video Stuff/bg2: HY1.9 (G2), U40.13 (B5)
/Denise & Video Stuff/bg3: HY1.8 (G3), RP402.7 (R4.1), U40.14 (B4)
/Denise & Video Stuff/bpixelsw: RP402.1 (R1.1), U41.13 (B5)
/Denise & Video Stuff/br0: HY1.6 (R0), U40.15 (B3)
/Denise & Video Stuff/br1: HY1.5 (R1), U40.16 (B2)
/Denise & Video Stuff/br2: HY1.4 (R2), U40.17 (B1)
/Denise & Video Stuff/br3: HY1.3 (R3), RP402.9 (R5.1), U40.18 (B0)
/Denise & Video Stuff/cck_c: E402.1, RP403.3 (R2.1)
/Denise & Video Stuff/csync_out: E434.1, JP11.2 (C)
/Denise & Video Stuff/hsync_buf: JP99H1.2 (B), RP403.5 (R3.1), U94.6
/Denise & Video Stuff/rbcsync_a: JP11.1 (A), RP403.10 (R5.2)
/Denise & Video Stuff/vsync_buf: JP99V1.2 (B), RP403.7 (R4.1), U94.8
CCK: U4.36 (CCK), U41.6 (A4); also elsewhere on the board
DRD0: U4.7 (DRD0); also elsewhere on the board
DRD1: U4.6 (DRD1); also elsewhere on the board
DRD2: U4.5 (DRD2); also elsewhere on the board
DRD3: U4.4 (DRD3); also elsewhere on the board
DRD4: U4.3 (DRD4); also elsewhere on the board
DRD5: U4.2 (DRD5); also elsewhere on the board
DRD6: U4.1 (DRD6); also elsewhere on the board
DRD7: U4.48 (DRD7); also elsewhere on the board
DRD8: U4.47 (DRD8); also elsewhere on the board
DRD9: U4.46 (DRD9); also elsewhere on the board
DRD10: U4.45 (DRD10); also elsewhere on the board
DRD11: U4.44 (DRD11); also elsewhere on the board
DRD12: U4.43 (DRD12); also elsewhere on the board
DRD13: U4.42 (DRD13); also elsewhere on the board
DRD14: U4.41 (DRD14); also elsewhere on the board
DRD15: U4.40 (DRD15); also elsewhere on the board
GND: C4.2, C40.2, C41.2, C94.2, C401.2, C402.2, C403.2, CN9.0 (PAD), CN9.13, CN9.16, CN9.17, CN9.18, CN9.19, CN9.20, CN10.1, E402.2, E403.2, E404.2, E405.2, E406.2, E431.2, E432.2, E433.2, E434.2, E435.2, HY1.1 (GND), HY1.22 (GND), R409.2, U4.37 (GND), U40.10 (GND), U40.19 (CE), U41.10 (GND), U41.19 (CE), U94.7 (GND); also elsewhere on the board
M0H: U4.9 (M0H); also elsewhere on the board
M0V: U4.38 (M0V); also elsewhere on the board
M1H: U4.8 (M1H); also elsewhere on the board
M1V: U4.39 (M1V); also elsewhere on the board
unnamed: C401.1, HY1.21 (VCC), R405.2
unnamed: CN9.14, RP402.2 (R1.2)
unnamed: CN9.15, E402.3
unnamed: CN9.21, E403.3
unnamed: CN9.22, E404.3
unnamed: CN9.23, E405.3
unnamed: CN9.3, E431.3
unnamed: CN9.4, E432.3
unnamed: CN9.5, E433.3
unnamed: CN9.10, E434.3
unnamed: CN10.2, E435.3, R409.1
unnamed: E435.1, HY1.19 (COMP_OUT)
unnamed: HY1.20 (SYNC_OUT), JP11.3 (B)
unnamed: HY2.2 (GATE), U4.18 (BURST)
unnamed: CN9.6, RP402.4 (R2.2)
unnamed: CN9.7, RP402.6 (R3.2)
unnamed: CN9.8, RP402.8 (R4.2)
unnamed: CN9.9, RP402.10 (R5.2)
unnamed: CN9.1, RP403.2 (R1.2)
unnamed: CN9.11, RP403.6 (R3.2)
unnamed: CN9.12, RP403.8 (R4.2)
unnamed: U4.23 (R3), U40.2 (A0)
unnamed: U4.22 (R2), U40.3 (A1)
unnamed: U4.21 (R1), U40.4 (A2)
unnamed: U4.20 (R0), U40.5 (A3)
unnamed: U4.31 (G3), U40.6 (A4)
unnamed: U4.30 (G2), U40.7 (A5)
unnamed: U4.29 (G1), U40.8 (A6)
unnamed: U4.28 (G0), U40.9 (A7)
unnamed: U4.27 (B3), U41.2 (A0)
unnamed: U4.26 (B2), U41.3 (A1)
unnamed: U4.25 (B1), U41.4 (A2)
unnamed: U4.24 (B0), U41.5 (A3)
unnamed: U4.33 (PIXELSW), U41.7 (A5)
unnamed: U94.4, U94.5
unnamed: U94.9, U94.10
RGA1: U4.17 (RGA1); also elsewhere on the board
RGA2: U4.16 (RGA2); also elsewhere on the board
RGA3: U4.15 (RGA3); also elsewhere on the board
RGA4: U4.14 (RGA4); also elsewhere on the board
RGA5: U4.13 (RGA5); also elsewhere on the board
RGA6: U4.12 (RGA6); also elsewhere on the board
RGA7: U4.11 (RGA7); also elsewhere on the board
RGA8: U4.10 (RGA8); also elsewhere on the board
VCC: E406.1, R402.1, R403.1, R404.1, R405.1; also elsewhere on the board
VD: C40.1, C41.1, C94.1, C402.1, HY1.2 (VCC), R406.1, U40.1 (A->B), U40.20 (VCC), U41.1 (A->B), U41.20 (VCC), U94.1, U94.13, U94.14 (VCC)
VDDA: C4.1, E405.1, E406.3, R406.2, U4.19 (VCC)
XCLK: R404.2, RP403.1 (R1.1); also elsewhere on the board
~CDAC: U4.34 (~CDAC); also elsewhere on the board
~CSYNC: U4.32 (BLANK), U41.8 (A6), U41.9 (A7); also elsewhere on the board
~HSYNC: JP99H1.1 (A), R402.2, U94.3; also elsewhere on the board
~VSYNC: JP99V1.1 (A), U94.11; also elsewhere on the board
~XCLKEN: CN9.2, R403.2; also elsewhere on the board

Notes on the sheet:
VIDEO POWER
VD (+VID on original schematics) is picked up here
1/2W
VDDA (+VXX on original schematics) is picked up here
+VXX = +12V supplied to video connector
+VID Power Supply
Note: Pin 2 and 21 of HY1 are connected internally on 390229-01 & 390229-02 hybrids
OPTIONAL ~{HSYNC}/~{VSYNC} BUFFERS
I'm pretty sure I've seen 4.7 used here as well...
R409 CONTROLS COMPOSITE OUTPUT LEVEL FOR 390229-01 HYBRID
I've never seen this actually installed on A500 boards

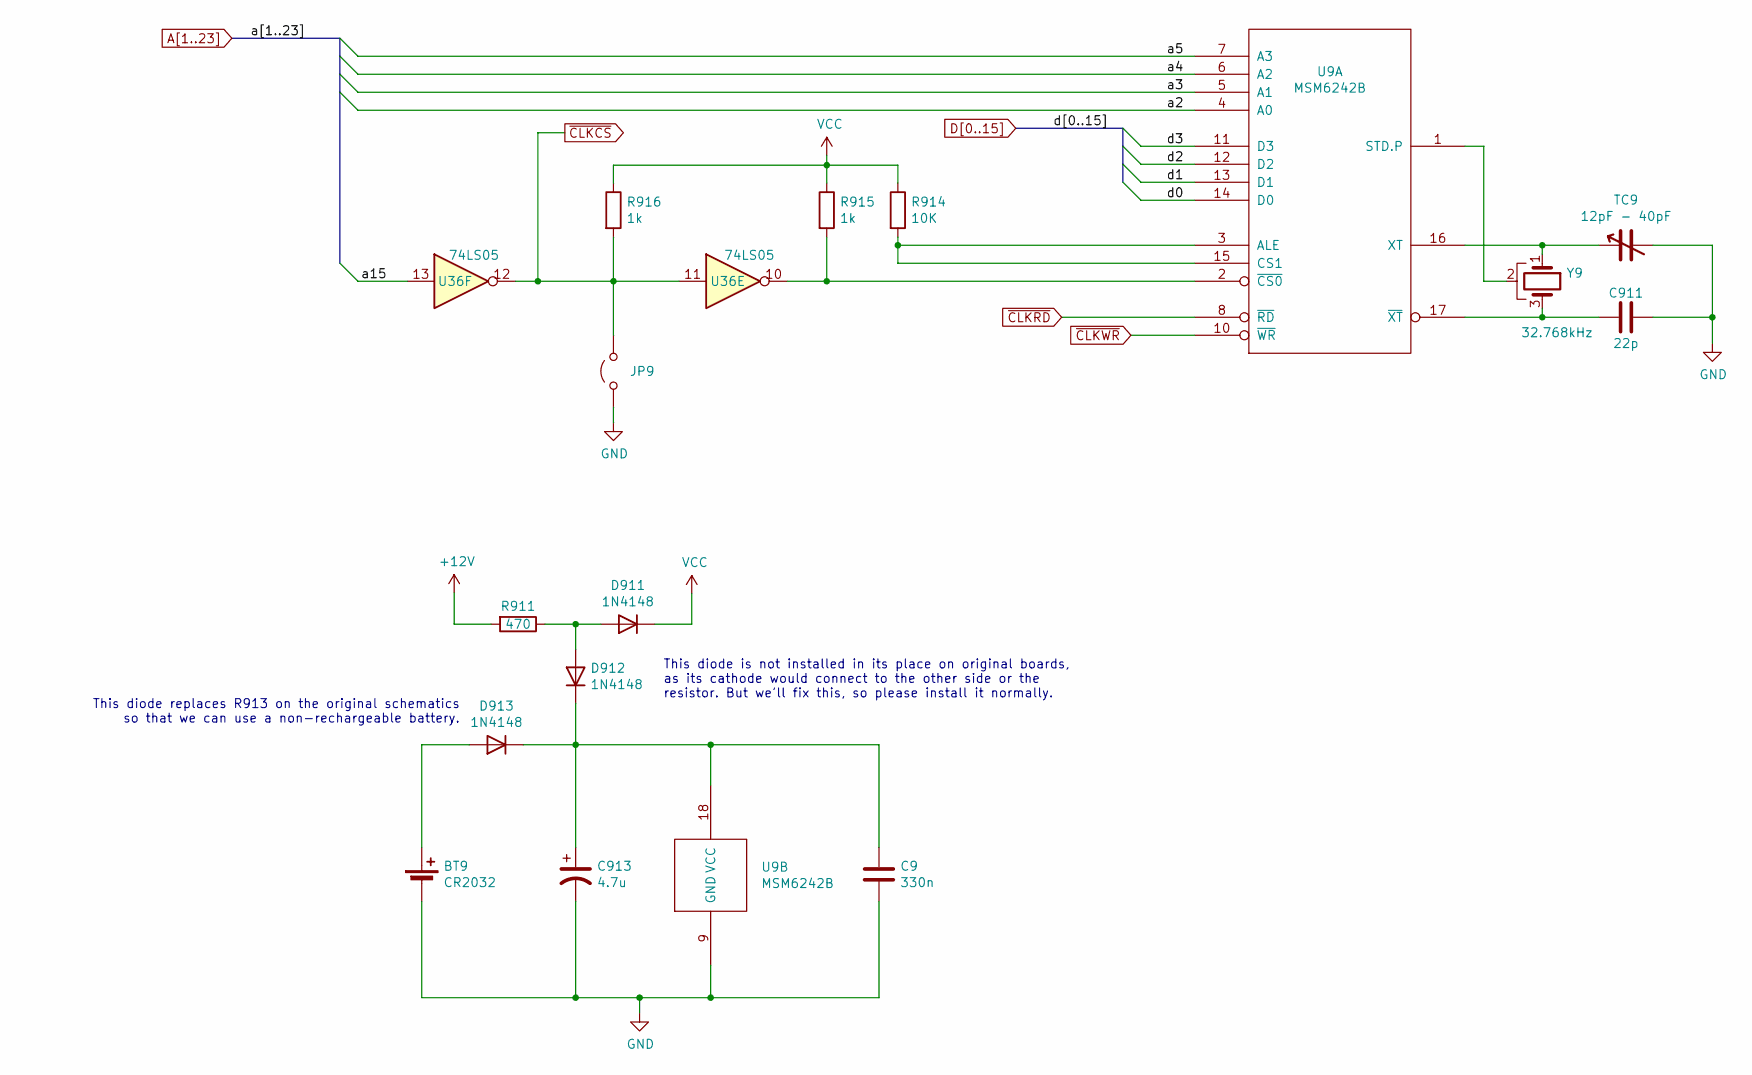
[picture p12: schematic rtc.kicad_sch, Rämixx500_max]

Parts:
BT9: CR2032; Battery_Holder_Coin_2032_BS-7; MFG Part Num 122-2420-GR; Mouser 122-2420-GR
C9: 330n; C_Axial_L6.3mm_D2.5mm_P10.16mm; MFG Part Num C440C334K5R5TA7200; Mouser 80-C440C334K5R-TR
C911: 22p; C_Axial_L6.3mm_D2.5mm_P10.16mm; MFG Part Num C410C220J1G5TA; Mouser 80-C410C220J1G
C913: 4.7u; CP_Radial_D8.0mm_P5.00mm; MFG Part Num ECA-2AM4R7B; Mouser 667-ECA-2AM4R7B
D911, D912, D913: 1N4148; D_DO-35_SOD27_P12.70mm_Horizontal; MFG Part Num 1N4148TR; Mouser 512-1N4148TR
JP9: Jumper_2_Open; Jumper2-Open; MFG Part Num SKIP
R911: 470; R_Axial_DIN0309_L9.0mm_D3.2mm_P12.70mm_Horizontal; MFG Part Num MFR-25FBF52-470R; Mouser 603-MFR-25FBF52-470R
R914: 10K; R_Axial_DIN0309_L9.0mm_D3.2mm_P12.70mm_Horizontal; MFG Part Num MFR-25FBF52-10K; Mouser 603-MFR-25FBF52-10K
R915, R916: 1k; R_Axial_DIN0309_L9.0mm_D3.2mm_P12.70mm_Horizontal; MFG Part Num MFR-25FBF52-1K; Mouser 603-MFR-25FBF52-1K
TC9: 12pF - 40pF; VariCap; MFG Part Num JML06-1 / 40PF / YELLOW
U9: MSM6242B; DIP-18_W7.62mm_Socket_LongPads; MFG Part Num 4818-3000-CP; Mouser 517-4818-3000-CP
U36: 74LS05; DIP-14_W7.62mm_LongPads; MFG Part Num SN74LS05N; Mouser 595-SN74LS05N
Y9: 32.768kHz; Crystal_RTC; MFG Part Num ECS-.327-12.5-13X; Mouser 520-TFC2X6-X

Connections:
+12V: R911.2; also elsewhere on the board
A2: U9.4 (A0); also elsewhere on the board
A3: U9.5 (A1); also elsewhere on the board
A4: U9.6 (A2); also elsewhere on the board
A5: U9.7 (A3); also elsewhere on the board
A15: U36.13; also elsewhere on the board
D0: U9.14 (D0); also elsewhere on the board
D1: U9.13 (D1); also elsewhere on the board
D2: U9.12 (D2); also elsewhere on the board
D3: U9.11 (D3); also elsewhere on the board
GND: BT9.2 (-), C9.2, C911.1, C913.2, JP9.1 (A), TC9.2, U9.9 (GND); also elsewhere on the board
unnamed: BT9.1 (+), D913.2 (A)
unnamed: D911.2 (A), D912.2 (A), R911.1
unnamed: C9.1, C913.1, D912.1 (K), D913.1 (K), U9.18 (VCC)
unnamed: R914.2, U9.3 (ALE), U9.15 (CS1)
unnamed: U9.1 (STD.P), Y9.2
unnamed: TC9.1, U9.16 (XT), Y9.1
unnamed: R915.2, U9.2 (~CS0), U36.10
unnamed: C911.2, U9.17 (~XT), Y9.3
VCC: D911.1 (K), R914.1, R915.1, R916.1; also elsewhere on the board
~CLKCS: JP9.2 (B), R916.2, U36.11, U36.12; also elsewhere on the board
~CLKRD: U9.8 (~RD); also elsewhere on the board
~CLKWR: U9.10 (~WR); also elsewhere on the board

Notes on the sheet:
This diode is not installed in its place on original boards, as its cathode would connect to the other side or the resistor. But we'll fix this, so please install it normally.
This diode replaces R913 on the original schematics so that we can use a non-rechargeable battery.

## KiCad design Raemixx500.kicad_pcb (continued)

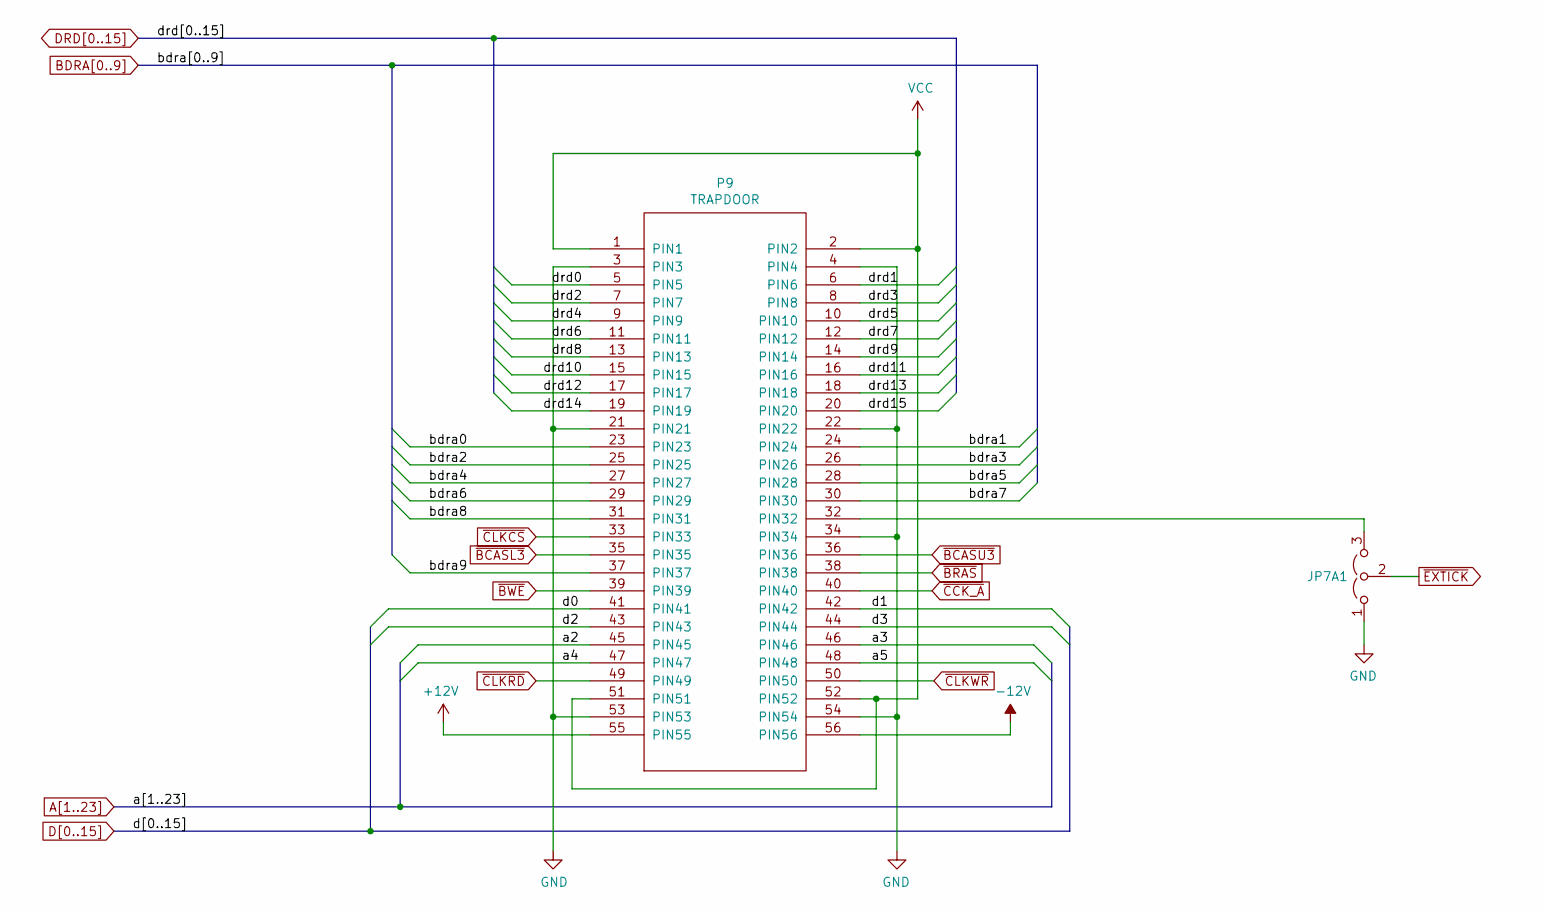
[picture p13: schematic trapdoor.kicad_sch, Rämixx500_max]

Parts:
JP7A1: Jumper_3_Open; Jumper3-Open; MFG Part Num SKIP
P9: TRAPDOOR; Trapdoor; MFG Part Num PH2RA-80-UA; Mouser 737-PH2RA-80-UA

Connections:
+12V: P9.55 (PIN55); also elsewhere on the board
-12V: P9.56 (PIN56); also elsewhere on the board
A2: P9.45 (PIN45); also elsewhere on the board
A3: P9.46 (PIN46); also elsewhere on the board
A4: P9.47 (PIN47); also elsewhere on the board
A5: P9.48 (PIN48); also elsewhere on the board
BDRA0: P9.23 (PIN23); also elsewhere on the board
BDRA1: P9.24 (PIN24); also elsewhere on the board
BDRA2: P9.25 (PIN25); also elsewhere on the board
BDRA3: P9.26 (PIN26); also elsewhere on the board
BDRA4: P9.27 (PIN27); also elsewhere on the board
BDRA5: P9.28 (PIN28); also elsewhere on the board
BDRA6: P9.29 (PIN29); also elsewhere on the board
BDRA7: P9.30 (PIN30); also elsewhere on the board
BDRA8: P9.31 (PIN31); also elsewhere on the board
BDRA9: P9.37 (PIN37); also elsewhere on the board
D0: P9.41 (PIN41); also elsewhere on the board
D1: P9.42 (PIN42); also elsewhere on the board
D2: P9.43 (PIN43); also elsewhere on the board
D3: P9.44 (PIN44); also elsewhere on the board
DRD0: P9.5 (PIN5); also elsewhere on the board
DRD1: P9.6 (PIN6); also elsewhere on the board
DRD2: P9.7 (PIN7); also elsewhere on the board
DRD3: P9.8 (PIN8); also elsewhere on the board
DRD4: P9.9 (PIN9); also elsewhere on the board
DRD5: P9.10 (PIN10); also elsewhere on the board
DRD6: P9.11 (PIN11); also elsewhere on the board
DRD7: P9.12 (PIN12); also elsewhere on the board
DRD8: P9.13 (PIN13); also elsewhere on the board
DRD9: P9.14 (PIN14); also elsewhere on the board
DRD10: P9.15 (PIN15); also elsewhere on the board
DRD11: P9.16 (PIN16); also elsewhere on the board
DRD12: P9.17 (PIN17); also elsewhere on the board
DRD13: P9.18 (PIN18); also elsewhere on the board
DRD14: P9.19 (PIN19); also elsewhere on the board
DRD15: P9.20 (PIN20); also elsewhere on the board
GND: JP7A1.1 (A), P9.3 (PIN3), P9.4 (PIN4), P9.21 (PIN21), P9.22 (PIN22), P9.34 (PIN34), P9.53 (PIN53), P9.54 (PIN54); also elsewhere on the board
unnamed: JP7A1.3 (B), P9.32 (PIN32)
VCC: P9.1 (PIN1), P9.2 (PIN2), P9.51 (PIN51), P9.52 (PIN52); also elsewhere on the board
~BCASL3: P9.35 (PIN35); also elsewhere on the board
~BCASU3: P9.36 (PIN36); also elsewhere on the board
~BRAS: P9.38 (PIN38); also elsewhere on the board
~BWE: P9.39 (PIN39); also elsewhere on the board
~CCK_A: P9.40 (PIN40); also elsewhere on the board
~CLKCS: P9.33 (PIN33); also elsewhere on the board
~CLKRD: P9.49 (PIN49); also elsewhere on the board
~CLKWR: P9.50 (PIN50); also elsewhere on the board
~EXTICK: JP7A1.2 (C); also elsewhere on the board

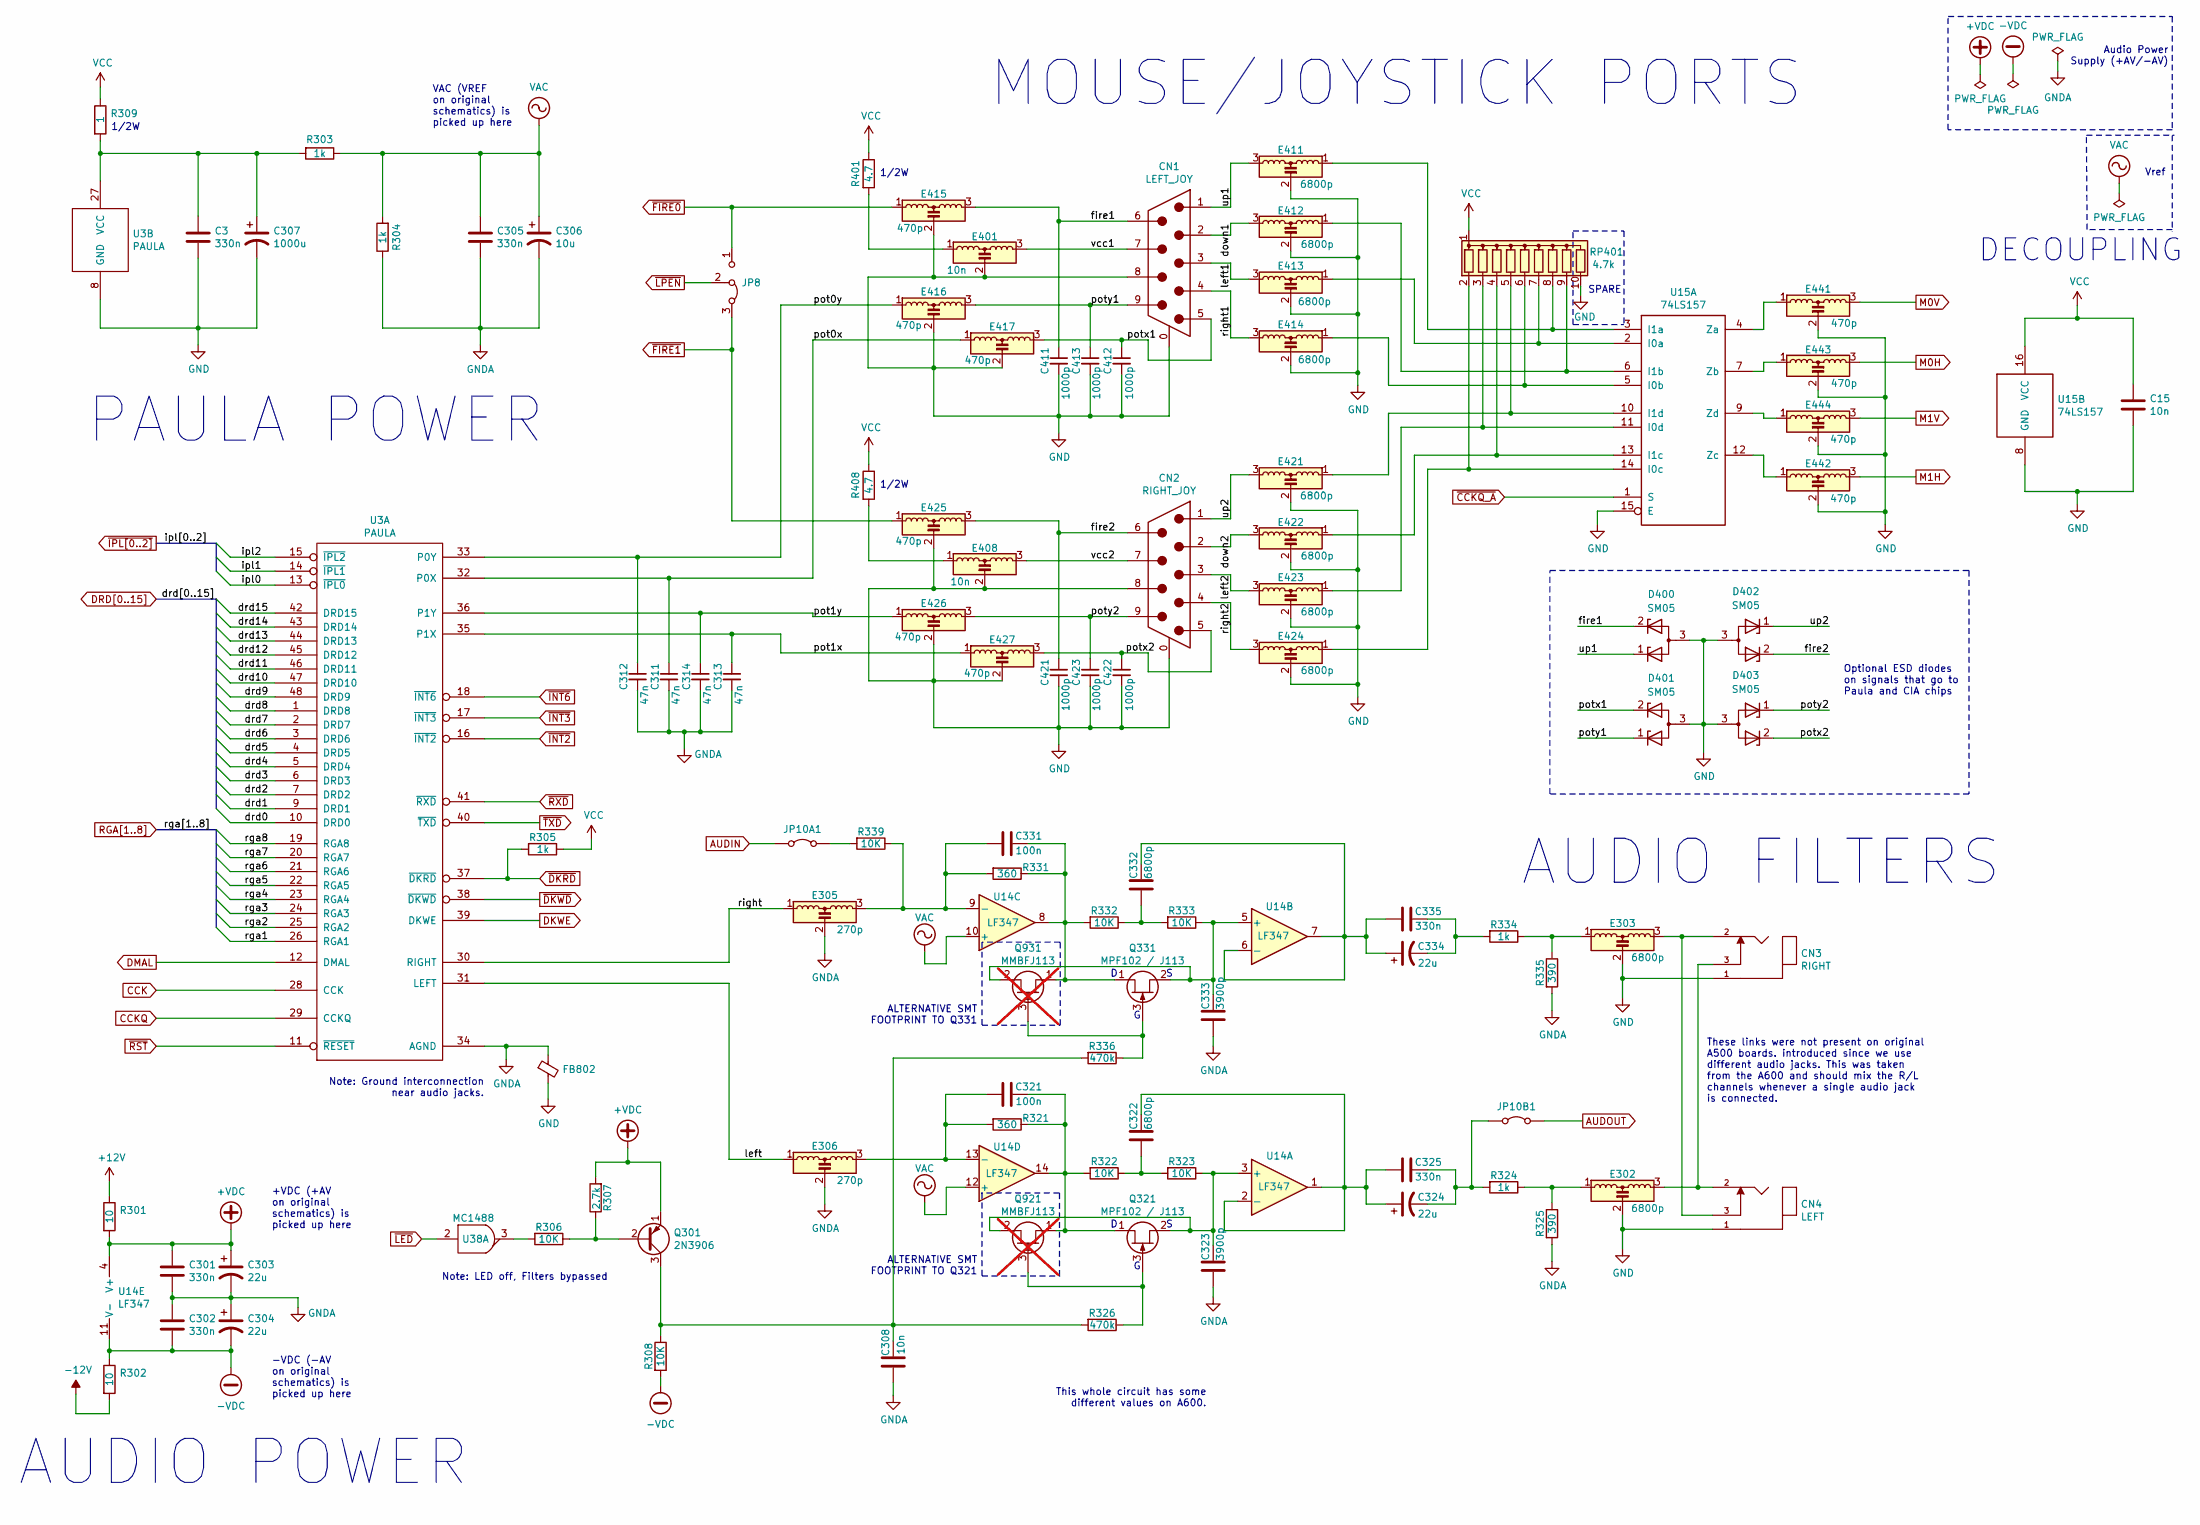
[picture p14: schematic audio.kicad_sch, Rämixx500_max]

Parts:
C3: 330n; C_Axial_L6.3mm_D2.5mm_P10.16mm; MFG Part Num C440C334K5R5TA7200; Mouser 80-C440C334K5R-TR
C15: 10n; C_Axial_L6.3mm_D2.5mm_P10.16mm; MFG Part Num C410C103K1R5TA; Mouser 80-C410C103K1R
C301, C302, C305, C325, C335: 330n; C_Axial_L9.0mm_D3.2mm_P12.70mm; MFG Part Num C440C334K5R5TA7200; Mouser 80-C440C334K5R-TR
C303, C304: 22u; CP_Radial_D5.0mm_P2.50mm; MFG Part Num ECA-1EM220I; Mouser 667-ECA-1EM220I
C306: 10u; CP_Radial_D5.0mm_P2.50mm; MFG Part Num ECA-1EM100I; Mouser 667-ECA-1EM100I
C307: 1000u; CP_Radial_D12.5mm_P5.00mm; MFG Part Num ECA-1EM102; Mouser 667-ECA-1EM102
C308: 10n; C_Axial_L9.0mm_D3.2mm_P12.70mm; MFG Part Num C410C103K1R5TA; Mouser 80-C410C103K1R
C311, C312, C313, C314: 47n; C_Axial_L9.0mm_D3.2mm_P12.70mm; MFG Part Num C410C473M5R5TA7200; Mouser 80-C410C473M5R-TR
C321, C331: 100n; C_Axial_L9.0mm_D3.2mm_P12.70mm; MFG Part Num A104K15X7RF5TAA; Mouser 594-A104K15X7RF5TAA
C322, C332: 6800p; C_Axial_L9.0mm_D3.2mm_P12.70mm; MFG Part Num C410C682K2R5TA7200; Mouser 80-C410C682K2R5TATU
C323, C333: 3900p; C_Axial_L9.0mm_D3.2mm_P12.70mm; MFG Part Num C410C392K1R5TA; Mouser 80-C410C392K1R
C324, C334: 22u; CP_Radial_D8.0mm_P5.00mm; MFG Part Num ECA-1EM220B; Mouser 667-ECA-1EM220B
C411, C412, C413, C421, C422, C423: 1000p; C_Axial_L9.0mm_D3.2mm_P12.70mm; MFG Part Num C410C102M5R5TA7200; Mouser 80-C410C102M5R-TR
CN1: LEFT_JOY; DB_9M; MFG Part Num L17HTNEP4F1C; Mouser 523-L17HTNEP4F1C
CN2: RIGHT_JOY; DB_9M; MFG Part Num L17HTNEP4F1C; Mouser 523-L17HTNEP4F1C
CN3: RIGHT; SWITCHCRAFT_PJRAN1X1U01X; MFG Part Num PJRAN1X1U01AUX; Mouser 502-PJRAN1X1U01AUX
CN4: LEFT; SWITCHCRAFT_PJRAN1X1U01X; MFG Part Num PJRAN1X1U01AUX; Mouser 502-PJRAN1X1U01AUX
D400, D401, D402, D403: SM05; SOT-23_Handsoldering_NoSilk; MFG Part Num SM05-7; Mouser 621-SM05-7
E302, E303: 6800p; EMI_Filter_Short; MFG Part Num DSS1NB32A682Q91A; Mouser 81-DSS1NB32A682Q91A
E305, E306: 270p; EMI_Filter_Long; MFG Part Num DSS1NB32A271Q91A; Mouser 81-DSS1NB32A271Q91A
E401, E408: 10n; EMI_Filter_Long; MFG Part Num DSS1NB32A103Q91A; Mouser 81-DSS1NB32A103Q91A
E411, E412, E413, E414, E421, E422, E423, E424: 6800p; EMI_Filter_Long; MFG Part Num DSS1NB32A682Q91A; Mouser 81-DSS1NB32A682Q91A
E415, E416, E417, E425, E426, E427, E441, E442, E443, E444: 470p; EMI_Filter_Long; MFG Part Num DSS1NB32A471Q91A; Mouser 81-DSS1NB32A471Q91A
FB802: Ferrite_Bead_Small; Ferrite_Axial_L9.0mm_D3.2mm_P12.70mm; MFG Part Num 2743007111; Mouser 623-2743007111
JP8: Jumper_3_Bridged23; Jumper3-Bridged23; MFG Part Num SKIP
JP10A1, JP10B1: Jumper_2_Bridged; Jumper2-Bridged; MFG Part Num SKIP
Q301: 2N3906; TO-92L_Inline_Wide; MFG Part Num 2N3906BU; Mouser 512-2N3906BU
Q321, Q331: MPF102 / J113; TO-92L_Inline_Wide; MFG Part Num J113; Mouser 512-J113
Q921, Q931: MMBFJ113; SOT-23_LongerPads; not fitted
R301, R302: 10; R_Axial_DIN0309_L9.0mm_D3.2mm_P12.70mm_Horizontal; MFG Part Num MFR-25FBF52-10R; Mouser 603-MFR-25FBF52-10R
R303, R304, R305, R324, R334: 1k; R_Axial_DIN0309_L9.0mm_D3.2mm_P12.70mm_Horizontal; MFG Part Num MFR-25FBF52-1K; Mouser 603-MFR-25FBF52-1K
R306, R308, R322, R323, R332, R333, R339: 10K; R_Axial_DIN0309_L9.0mm_D3.2mm_P12.70mm_Horizontal; MFG Part Num MFR-25FBF52-10K; Mouser 603-MFR-25FBF52-10K
R307: 2.7k; R_Axial_DIN0309_L9.0mm_D3.2mm_P12.70mm_Horizontal; MFG Part Num MFR-25FBF52-2K7; Mouser 603-MFR-25FBF52-2K7
R309: 1; R_Axial_DIN0309_L9.0mm_D3.2mm_P15.24mm_Horizontal; MFG Part Num PR01000101008JA500; Mouser 594-PR01000101008JA5
R321, R331: 360; R_Axial_DIN0309_L9.0mm_D3.2mm_P12.70mm_Horizontal; MFG Part Num MFR-25FRF52-360R; Mouser 603-MFR-25FRF52-360R
R325, R335: 390; R_Axial_DIN0309_L9.0mm_D3.2mm_P12.70mm_Horizontal; MFG Part Num MFR-25FBF52-390R; Mouser 603-MFR-25FBF52-390R
R326, R336: 470k; R_Axial_DIN0309_L9.0mm_D3.2mm_P12.70mm_Horizontal; MFG Part Num MFR-25FBF52-470K; Mouser 603-MFR-25FBF52-470K
R401, R408: 4.7; R_Axial_DIN0309_L9.0mm_D3.2mm_P15.24mm_Horizontal; MFG Part Num PR01000104708JA500; Mouser 594-PR01000104708JA5
RP401: 4.7k; R_Array_SIP10; MFG Part Num 4610X-101-472LF; Mouser 652-4610X-1LF-4.7K
U3: PAULA; DIP-48_W15.24mm_Socket_LongPads; MFG Part Num 4848-6000-CP; Mouser 517-4848-6000-CP
U14: LF347; DIP-14_W7.62mm_LongPads; MFG Part Num LF347N; Mouser 595-LF347N
U15: 74LS157; DIP-16_W7.62mm_LongPads; MFG Part Num SN74LS157N; Mouser 595-SN74LS157N
U38: MC1488; DIP-14_W7.62mm_LongPads; MFG Part Num SN75C188N; Mouser 595-SN75C188N

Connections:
+12V: R301.1; also elsewhere on the board
+VDC: C301.1, C303.1, Q301.1 (E), R301.2, R307.2, U14.4 (V+)
-12V: R302.2; also elsewhere on the board
-VDC: C302.2, C304.2, R302.1, R308.2, U14.11 (V-)
/Paula & Audio Stuff/down1: CN1.2, E412.3
/Paula & Audio Stuff/down2: CN2.2, E422.3
/Paula & Audio Stuff/fire1: C411.1, CN1.6, D400.2 (K), E415.3
/Paula & Audio Stuff/fire2: C421.1, CN2.6, D402.2 (K), E425.3
/Paula & Audio Stuff/left: E306.1, U3.31 (LEFT)
/Paula & Audio Stuff/left1: CN1.3, E413.3
/Paula & Audio Stuff/left2: CN2.3, E423.3
/Paula & Audio Stuff/pot0x: C311.1, E417.1, U3.32 (P0X)
/Paula & Audio Stuff/pot0y: C312.1, E416.1, U3.33 (P0Y)
/Paula & Audio Stuff/pot1x: C313.1, E427.1, U3.35 (P1X)
/Paula & Audio Stuff/pot1y: C314.1, E426.1, U3.36 (P1Y)
/Paula & Audio Stuff/potx1: C412.1, CN1.5, D401.2 (K), E417.3
/Paula & Audio Stuff/potx2: C422.1, CN2.5, D403.2 (K), E427.3
/Paula & Audio Stuff/poty1: C413.1, CN1.9, D401.1 (K), E416.3
/Paula & Audio Stuff/poty2: C423.1, CN2.9, D403.1 (K), E426.3
/Paula & Audio Stuff/right: E305.1, U3.30 (RIGHT)
/Paula & Audio Stuff/right1: CN1.4, E414.3
/Paula & Audio Stuff/right2: CN2.4, E424.3
/Paula & Audio Stuff/up1: CN1.1, D400.1 (K), E411.3
/Paula & Audio Stuff/up2: CN2.1, D402.1 (K), E421.3
/Paula & Audio Stuff/vcc1: CN1.7, E401.3
/Paula & Audio Stuff/vcc2: CN2.7, E408.3
AUDIN: JP10A1.1 (A); also elsewhere on the board
AUDOUT: JP10B1.2 (B); also elsewhere on the board
CCK: U3.28 (CCK); also elsewhere on the board
CCKQ: U3.29 (CCKQ); also elsewhere on the board
DKWE: U3.39 (DKWE); also elsewhere on the board
DMAL: U3.12 (DMAL); also elsewhere on the board
DRD0: U3.10 (DRD0); also elsewhere on the board
DRD1: U3.9 (DRD1); also elsewhere on the board
DRD2: U3.7 (DRD2); also elsewhere on the board
DRD3: U3.6 (DRD3); also elsewhere on the board
DRD4: U3.5 (DRD4); also elsewhere on the board
DRD5: U3.4 (DRD5); also elsewhere on the board
DRD6: U3.3 (DRD6); also elsewhere on the board
DRD7: U3.2 (DRD7); also elsewhere on the board
DRD8: U3.1 (DRD8); also elsewhere on the board
DRD9: U3.48 (DRD9); also elsewhere on the board
DRD10: U3.47 (DRD10); also elsewhere on the board
DRD11: U3.46 (DRD11); also elsewhere on the board
DRD12: U3.45 (DRD12); also elsewhere on the board
DRD13: U3.44 (DRD13); also elsewhere on the board
DRD14: U3.43 (DRD14); also elsewhere on the board
DRD15: U3.42 (DRD15); also elsewhere on the board
GND: C3.2, C15.2, C307.2, C411.2, C412.2, C413.2, C421.2, C422.2, C423.2, CN1.0 (PAD), CN1.8, CN2.0 (PAD), CN2.8, CN3.1, CN4.1, D400.3 (A), D401.3 (A), D402.3 (A), D403.3 (A), E302.2, E303.2, E401.2, E408.2, E411.2, E412.2, E413.2, E414.2, E415.2, E416.2, E417.2, E421.2, E422.2, E423.2, E424.2, E425.2, E426.2, E427.2, E441.2, E442.2, E443.2, E444.2, FB802.2, RP401.10 (R9), U3.8 (GND), U15.8 (GND), U15.15 (E); also elsewhere on the board
GNDA: C301.2, C302.1, C303.2, C304.1, C305.2, C306.2, C308.2, C311.2, C312.2, C313.2, C314.2, C323.2, C333.2, E305.2, E306.2, FB802.1, R304.1, R325.2, R335.2, U3.34 (AGND)
M0H: E443.3; also elsewhere on the board
M0V: E441.3; also elsewhere on the board
M1H: E442.3; also elsewhere on the board
M1V: E444.3; also elsewhere on the board
unnamed: C322.2, R322.1, R323.2
unnamed: C332.2, R332.1, R333.2
unnamed: C334.2, C335.1, R334.2
unnamed: CN3.2, CN4.3, E303.3
unnamed: CN3.3, CN4.2, E302.3
unnamed: E302.1, R324.1, R325.1
unnamed: E303.1, R334.1, R335.1
unnamed: E401.1, R401.2
unnamed: E408.1, R408.2
unnamed: JP10A1.2 (B), R339.2
unnamed: C324.2, C325.1, JP10B1.1 (A), R324.2
unnamed: Q301.2 (B), R306.1, R307.1
unnamed: C308.1, Q301.3 (C), R308.1, R326.2, R336.2
unnamed: C321.1, Q321.1 (D), Q921.1 (D), R321.1, R322.2, U14.14
unnamed: Q321.3 (G), Q921.3 (G), R326.1
unnamed: C323.1, Q321.2 (S), Q921.2 (S), R323.1, U14.3 (+)
unnamed: C331.1, Q331.1 (D), Q931.1 (D), R331.1, R332.2, U14.8
unnamed: Q331.3 (G), Q931.3 (G), R336.1
unnamed: C333.1, Q331.2 (S), Q931.2 (S), R333.1, U14.5 (+)
unnamed: R306.2, U38.3
unnamed: E424.1, RP401.2 (R1), U15.14 (I0c)
unnamed: E423.1, RP401.3 (R2), U15.11 (I0d)
unnamed: E422.1, RP401.4 (R3), U15.13 (I1c)
unnamed: E421.1, RP401.5 (R4), U15.10 (I1d)
unnamed: E414.1, RP401.6 (R5), U15.5 (I0b)
unnamed: E413.1, RP401.7 (R6), U15.2 (I0a)
unnamed: E411.1, RP401.8 (R7), U15.3 (I1a)
unnamed: E412.1, RP401.9 (R8), U15.6 (I1b)
unnamed: C3.1, C307.1, R303.2, R309.2, U3.27 (VCC)
unnamed: C322.1, C324.1, C325.2, U14.1, U14.2 (-)
unnamed: C332.1, C334.1, C335.2, U14.6 (-), U14.7
unnamed: C331.2, E305.3, R331.2, R339.1, U14.9 (-)
unnamed: C321.2, E306.3, R321.2, U14.13 (-)
unnamed: E441.1, U15.4 (Za)
unnamed: E443.1, U15.7 (Zb)
unnamed: E442.1, U15.12 (Zc)
unnamed: E444.1, U15.9 (Zd)
RGA1: U3.26 (RGA1); also elsewhere on the board
RGA2: U3.25 (RGA2); also elsewhere on the board
RGA3: U3.24 (RGA3); also elsewhere on the board
RGA4: U3.23 (RGA4); also elsewhere on the board
RGA5: U3.22 (RGA5); also elsewhere on the board
RGA6: U3.21 (RGA6); also elsewhere on the board
RGA7: U3.20 (RGA7); also elsewhere on the board
RGA8: U3.19 (RGA8); also elsewhere on the board
VAC: C305.1, C306.1, R303.1, R304.2, U14.10 (+), U14.12 (+)
VCC: C15.1, R305.1, R309.1, R401.1, R408.1, RP401.1 (common), U15.16 (VCC); also elsewhere on the board
~CCKQ_A: U15.1 (S); also elsewhere on the board
~DKRD: R305.2, U3.37 (~DKRD); also elsewhere on the board
~DKWD: U3.38 (~DKWD); also elsewhere on the board
~FIRE0: E415.1, JP8.1 (A); also elsewhere on the board
~FIRE1: E425.1, JP8.3 (B); also elsewhere on the board
~INT2: U3.16 (~INT2); also elsewhere on the board
~INT3: U3.17 (~INT3); also elsewhere on the board
~INT6: U3.18 (~INT6); also elsewhere on the board
~IPL0: U3.13 (~IPL0); also elsewhere on the board
~IPL1: U3.14 (~IPL1); also elsewhere on the board
~IPL2: U3.15 (~IPL2); also elsewhere on the board
~LED: U38.2; also elsewhere on the board
~LPEN: JP8.2 (C); also elsewhere on the board
~RST: U3.11 (~RESET); also elsewhere on the board
~RXD: U3.41 (~RXD); also elsewhere on the board
~TXD: U3.40 (~TXD); also elsewhere on the board

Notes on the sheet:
DECOUPLING
Optional ESD diodes on signals that go to Paula and CIA chips
Note: LED off, Filters bypassed
AUDIO POWER
ALTERNATIVE SMT FOOTPRINT TO Q331
Vref
1/2W
VAC (VREF on original schematics) is picked up here
These links were not present on original A500 boards. introduced since we use different audio jacks. This was taken from the A600 and should mix the R/L channels whenever a single audio jack is connected.
Audio Power Supply (+AV/-AV)
SPARE
+VDC (+AV on original schematics) is picked up here
-VDC (-AV on original schematics) is picked up here
This whole circuit has some different values on A600.
PAULA POWER
AUDIO FILTERS
ALTERNATIVE SMT FOOTPRINT TO Q321
MOUSE/JOYSTICK PORTS
Note: Ground interconnection near audio jacks.

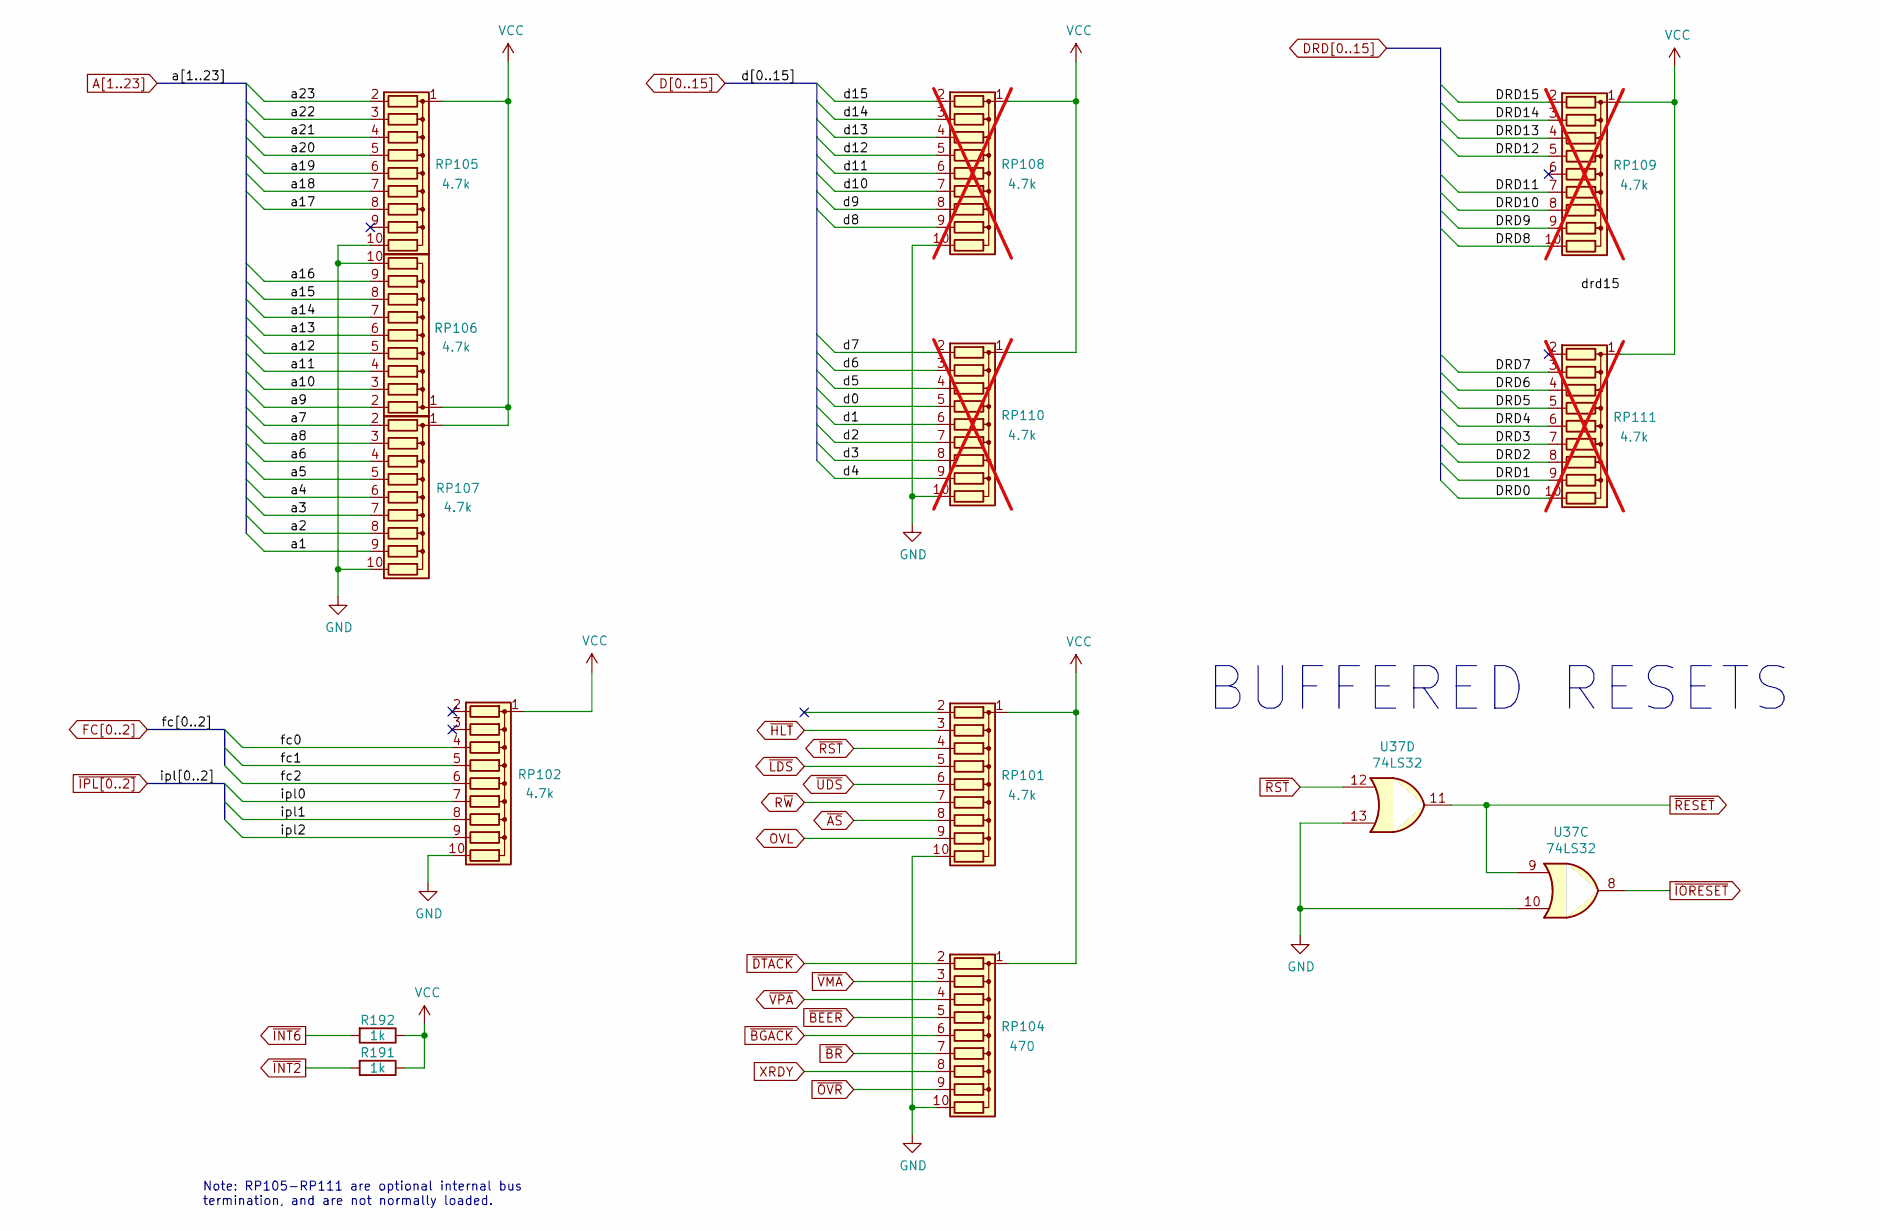
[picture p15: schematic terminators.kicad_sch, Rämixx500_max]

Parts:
R191, R192: 1k; R_Axial_DIN0309_L9.0mm_D3.2mm_P12.70mm_Horizontal; MFG Part Num MFR-25FBF52-1K; Mouser 603-MFR-25FBF52-1K
RP101, RP102, RP105, RP106, RP107: 4.7k; R_Array_SIP10; MFG Part Num 4610X-101-472LF; Mouser 652-4610X-1LF-4.7K
RP104: 470; R_Array_SIP10; MFG Part Num 4610X-101-471LF; Mouser 652-4610X-1LF-470
RP108, RP109, RP110, RP111: 4.7k; R_Array_SIP10; not fitted
U37: 74LS32; DIP-14_W7.62mm_LongPads; MFG Part Num SN74LS32N; Mouser 595-SN74LS32N

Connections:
A1: RP107.9 (R8); also elsewhere on the board
A2: RP107.8 (R7); also elsewhere on the board
A3: RP107.7 (R6); also elsewhere on the board
A4: RP107.6 (R5); also elsewhere on the board
A5: RP107.5 (R4); also elsewhere on the board
A6: RP107.4 (R3); also elsewhere on the board
A7: RP107.2 (R1); also elsewhere on the board
A8: RP107.3 (R2); also elsewhere on the board
A9: RP106.2 (R1); also elsewhere on the board
A10: RP106.3 (R2); also elsewhere on the board
A11: RP106.4 (R3); also elsewhere on the board
A12: RP106.5 (R4); also elsewhere on the board
A13: RP106.6 (R5); also elsewhere on the board
A14: RP106.7 (R6); also elsewhere on the board
A15: RP106.8 (R7); also elsewhere on the board
A16: RP106.9 (R8); also elsewhere on the board
A17: RP105.8 (R7); also elsewhere on the board
A18: RP105.7 (R6); also elsewhere on the board
A19: RP105.6 (R5); also elsewhere on the board
A20: RP105.5 (R4); also elsewhere on the board
A21: RP105.4 (R3); also elsewhere on the board
A22: RP105.3 (R2); also elsewhere on the board
A23: RP105.2 (R1); also elsewhere on the board
D0: RP110.5 (R4); also elsewhere on the board
D1: RP110.6 (R5); also elsewhere on the board
D2: RP110.7 (R6); also elsewhere on the board
D3: RP110.8 (R7); also elsewhere on the board
D4: RP110.9 (R8); also elsewhere on the board
D5: RP110.4 (R3); also elsewhere on the board
D6: RP110.3 (R2); also elsewhere on the board
D7: RP110.2 (R1); also elsewhere on the board
D8: RP108.9 (R8); also elsewhere on the board
D9: RP108.8 (R7); also elsewhere on the board
D10: RP108.7 (R6); also elsewhere on the board
D11: RP108.6 (R5); also elsewhere on the board
D12: RP108.5 (R4); also elsewhere on the board
D13: RP108.4 (R3); also elsewhere on the board
D14: RP108.3 (R2); also elsewhere on the board
D15: RP108.2 (R1); also elsewhere on the board
DRD0: RP111.10 (R9); also elsewhere on the board
DRD1: RP111.9 (R8); also elsewhere on the board
DRD2: RP111.8 (R7); also elsewhere on the board
DRD3: RP111.7 (R6); also elsewhere on the board
DRD4: RP111.6 (R5); also elsewhere on the board
DRD5: RP111.5 (R4); also elsewhere on the board
DRD6: RP111.4 (R3); also elsewhere on the board
DRD7: RP111.3 (R2); also elsewhere on the board
DRD8: RP109.10 (R9); also elsewhere on the board
DRD9: RP109.9 (R8); also elsewhere on the board
DRD10: RP109.8 (R7); also elsewhere on the board
DRD11: RP109.7 (R6); also elsewhere on the board
DRD12: RP109.5 (R4); also elsewhere on the board
DRD13: RP109.4 (R3); also elsewhere on the board
DRD14: RP109.3 (R2); also elsewhere on the board
DRD15: RP109.2 (R1); also elsewhere on the board
FC0: RP102.4 (R3); also elsewhere on the board
FC1: RP102.5 (R4); also elsewhere on the board
FC2: RP102.6 (R5); also elsewhere on the board
GND: RP101.10 (R9), RP102.10 (R9), RP104.10 (R9), RP105.10 (R9), RP106.10 (R9), RP107.10 (R9), RP108.10 (R9), RP110.10 (R9), U37.10, U37.13; also elsewhere on the board
OVL: RP101.9 (R8); also elsewhere on the board
R~W: RP101.7 (R6); also elsewhere on the board
VCC: R191.1, R192.1, RP101.1 (common), RP102.1 (common), RP104.1 (common), RP105.1 (common), RP106.1 (common), RP107.1 (common), RP108.1 (common), RP109.1 (common), RP110.1 (common), RP111.1 (common); also elsewhere on the board
XRDY: RP104.8 (R7); also elsewhere on the board
~AS: RP101.8 (R7); also elsewhere on the board
~BEER: RP104.5 (R4); also elsewhere on the board
~BGACK: RP104.6 (R5); also elsewhere on the board
~BR: RP104.7 (R6); also elsewhere on the board
~DTACK: RP104.2 (R1); also elsewhere on the board
~HLT: RP101.3 (R2); also elsewhere on the board
~INT2: R191.2; also elsewhere on the board
~INT6: R192.2; also elsewhere on the board
~IORESET: U37.8; also elsewhere on the board
~IPL0: RP102.7 (R6); also elsewhere on the board
~IPL1: RP102.8 (R7); also elsewhere on the board
~IPL2: RP102.9 (R8); also elsewhere on the board
~LDS: RP101.5 (R4); also elsewhere on the board
~OVR: RP104.9 (R8); also elsewhere on the board
~RESET: U37.9, U37.11; also elsewhere on the board
~RST: RP101.4 (R3), U37.12; also elsewhere on the board
~UDS: RP101.6 (R5); also elsewhere on the board
~VMA: RP104.3 (R2); also elsewhere on the board
~VPA: RP104.4 (R3); also elsewhere on the board

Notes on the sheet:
Note: RP105-RP111 are optional internal bus termination, and are not normally loaded.
BUFFERED RESETS

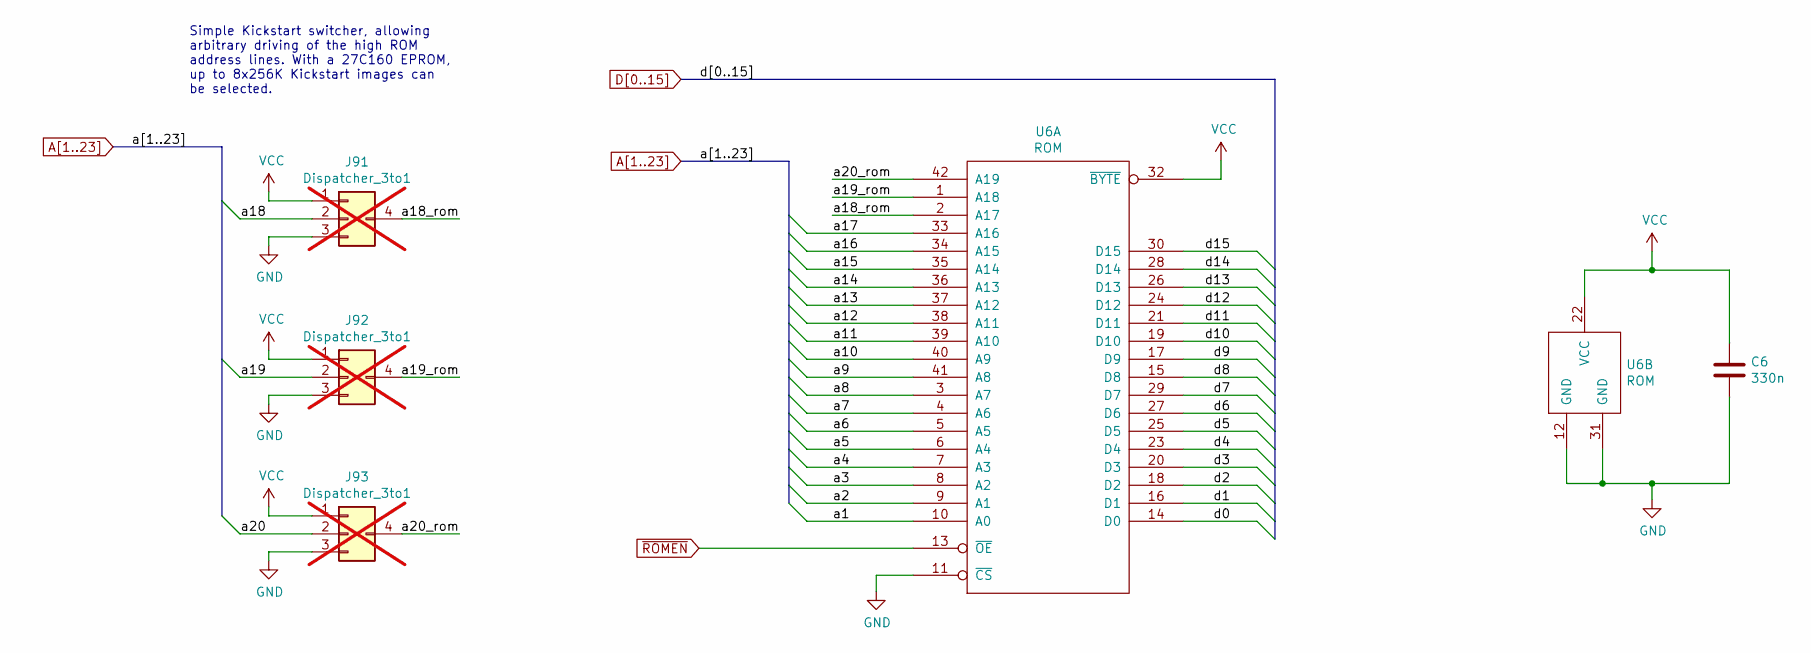
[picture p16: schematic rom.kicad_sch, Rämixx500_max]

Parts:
C6: 330n; C_Axial_L6.3mm_D2.5mm_P10.16mm; MFG Part Num C440C334K5R5TA7200; Mouser 80-C440C334K5R-TR
J91, J92, J93: Dispatcher_3to1; not fitted
U6: ROM; DIP-42_W15.24mm_Socket_LongPads; MFG Part Num 4842-6000-CP; Mouser 517-4842-6000-CP

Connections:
/Kickstart ROM/a18_rom: J91.4 (Out), U6.2 (A17)
/Kickstart ROM/a19_rom: J92.4 (Out), U6.1 (A18)
/Kickstart ROM/a20_rom: J93.4 (Out), U6.42 (A19)
A1: U6.10 (A0); also elsewhere on the board
A2: U6.9 (A1); also elsewhere on the board
A3: U6.8 (A2); also elsewhere on the board
A4: U6.7 (A3); also elsewhere on the board
A5: U6.6 (A4); also elsewhere on the board
A6: U6.5 (A5); also elsewhere on the board
A7: U6.4 (A6); also elsewhere on the board
A8: U6.3 (A7); also elsewhere on the board
A9: U6.41 (A8); also elsewhere on the board
A10: U6.40 (A9); also elsewhere on the board
A11: U6.39 (A10); also elsewhere on the board
A12: U6.38 (A11); also elsewhere on the board
A13: U6.37 (A12); also elsewhere on the board
A14: U6.36 (A13); also elsewhere on the board
A15: U6.35 (A14); also elsewhere on the board
A16: U6.34 (A15); also elsewhere on the board
A17: U6.33 (A16); also elsewhere on the board
A18: J91.2 (In_2); also elsewhere on the board
A19: J92.2 (In_2); also elsewhere on the board
A20: J93.2 (In_2); also elsewhere on the board
D0: U6.14 (D0); also elsewhere on the board
D1: U6.16 (D1); also elsewhere on the board
D2: U6.18 (D2); also elsewhere on the board
D3: U6.20 (D3); also elsewhere on the board
D4: U6.23 (D4); also elsewhere on the board
D5: U6.25 (D5); also elsewhere on the board
D6: U6.27 (D6); also elsewhere on the board
D7: U6.29 (D7); also elsewhere on the board
D8: U6.15 (D8); also elsewhere on the board
D9: U6.17 (D9); also elsewhere on the board
D10: U6.19 (D10); also elsewhere on the board
D11: U6.21 (D11); also elsewhere on the board
D12: U6.24 (D12); also elsewhere on the board
D13: U6.26 (D13); also elsewhere on the board
D14: U6.28 (D14); also elsewhere on the board
D15: U6.30 (D15); also elsewhere on the board
GND: C6.2, J91.3 (In_3), J92.3 (In_3), J93.3 (In_3), U6.11 (~CS), U6.12 (GND), U6.31 (GND); also elsewhere on the board
VCC: C6.1, J91.1 (In_1), J92.1 (In_1), J93.1 (In_1), U6.22 (VCC), U6.32 (~BYTE); also elsewhere on the board
~ROMEN: U6.13 (~OE); also elsewhere on the board

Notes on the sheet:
Simple Kickstart switcher, allowing arbitrary driving of the high ROM address lines. With a 27C160 EPROM, up to 8x256K Kickstart images can be selected.

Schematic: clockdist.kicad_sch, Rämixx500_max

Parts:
C33: 10n; C_Axial_L6.3mm_D2.5mm_P10.16mm; MFG Part Num C410C103K1R5TA; Mouser 80-C410C103K1R
E102, E103, E106, E107, E108: 47p; C_Axial_L9.0mm_D3.2mm_P12.70mm; MFG Part Num A470J15C0GF5TAA; Mouser 594-A470J15C0GF5TAA
E104, E105: 68; EMI_Filter_Long; MFG Part Num MFR-25FBF52-68R; Mouser 603-MFR-25FBF52-68R
E109, E791, E792, E793, E794: 47p; C_Axial_L6.3mm_D2.5mm_P10.16mm; MFG Part Num A470J15C0GF5TAA; Mouser 594-A470J15C0GF5TAA
E407: 10n; EMI_Filter_Short; MFG Part Num DSS1NB32A103Q91A; Mouser 81-DSS1NB32A103Q91A
RP103: 39; R_Array_SIP10; MFG Part Num 4610X-102-390LF; Mouser 652-4610X-2LF-39
U33: 74F258; DIP-16_W7.62mm_LongPads; MFG Part Num SN74F258N; Mouser 595-SN74F258N

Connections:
7MHZ: E103.1; also elsewhere on the board
7MHZ_A: E794.1; also elsewhere on the board
CCK: E108.1, U33.5, U33.6; also elsewhere on the board
CCKQ: E107.1, U33.10, U33.11; also elsewhere on the board
CDAC: E793.1, RP103.4 (R2.2); also elsewhere on the board
GND: C33.2, E102.2, E103.2, E104.2, E105.2, E106.2, E107.2, E108.2, E109.2, E407.2, E791.2, E792.2, E793.2, E794.2, U33.8 (GND), U33.15 (OE); also elsewhere on the board
unnamed: RP103.3 (R2.1), U33.4
unnamed: E104.1, RP103.5 (R3.1), U33.7
unnamed: E105.1, RP103.7 (R4.1), U33.9
unnamed: C33.1, E407.3, U33.16 (VCC)
VCC: E407.1; also elsewhere on the board
~CCKQ_A: E105.3, E109.1; also elsewhere on the board
~CCKQ: E791.1, RP103.8 (R4.2); also elsewhere on the board
~CCK_A: E102.1, E104.3; also elsewhere on the board
~CCK: E792.1, RP103.6 (R3.2); also elsewhere on the board
~CDAC: E106.1, U33.2, U33.3; also elsewhere on the board
~XCLKEN: U33.1 (S); also elsewhere on the board

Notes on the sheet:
FCC GOOBERS

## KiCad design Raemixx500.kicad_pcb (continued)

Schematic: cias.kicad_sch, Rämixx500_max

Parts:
C7, C8: 10n; C_Axial_L6.3mm_D2.5mm_P10.16mm; MFG Part Num C410C103K1R5TA; Mouser 80-C410C103K1R
C39, C713: 10n; C_Axial_L9.0mm_D3.2mm_P12.70mm; MFG Part Num C410C103K1R5TA; Mouser 80-C410C103K1R
C42: 330n; C_Axial_L6.3mm_D2.5mm_P10.16mm; MFG Part Num C440C334K5R5TA7200; Mouser 80-C440C334K5R-TR
C501, C502: 330n; C_Axial_L9.0mm_D3.2mm_P12.70mm; MFG Part Num C440C334K5R5TA7200; Mouser 80-C440C334K5R-TR
C711: 100n; C_Axial_L9.0mm_D3.2mm_P12.70mm; MFG Part Num A104K15X7RF5TAA; Mouser 594-A104K15X7RF5TAA
C712: 10u; CP_Radial_D5.0mm_P2.50mm; MFG Part Num ECA-1EM100I; Mouser 667-ECA-1EM100I
CN6: SERIAL_DB25M; DB_25M; MFG Part Num L717SDB25PA4CH4F; Mouser 523-L717SDB25PA4CH4F
CN7: PARALLEL_DB25F; DB_25F; MFG Part Num L77SDB25SA4CH4F; Mouser 523-L77SDB25SA4CH4F
CN13: KEYBOARD; Keyboard_Connector; MFG Part Num 10129378-908003BLF; Mouser 649-1012937890803BLF
D501: 1N4148; D_DO-35_SOD27_P12.70mm_Horizontal; MFG Part Num 1N4148TR; Mouser 512-1N4148TR
E501, E502, E503: 47 1/2W; EMI_Filter_Longer; MFG Part Num PR01000104709JA500; Mouser 594-PR01000104709JA5
E511, E512, E513, E514, E515, E516, E517, E518, E519, E521, E522, E523, E524, E631, E632: 100p; EMI_Filter_Short; MFG Part Num DSS1NB32A101Q91A; Mouser 81-DSS1NB32A101Q91A
E520, E531, E533, E535, E536, E537, E538: 470p; EMI_Filter_Short; MFG Part Num DSS1NB32A471Q91A; Mouser 81-DSS1NB32A471Q91A
E532, E534: 150p; EMI_Filter_Short; MFG Part Num DSS1NB32A151Q91A; Mouser 81-DSS1NB32A151Q91A
J90: DRIVE_SWITCHER; DriveSwitchHeader; not fitted
J99: HD_ACT; PinHeader_1x02_P2.54mm_Vertical; MFG Part Num 10129378-902003BLF; Mouser 649-1012937890203BLF
JP1: Jumper_2_Bridged; Jumper2-Bridged; MFG Part Num SKIP
JP7B1: Jumper_3_Bridged23; Jumper3-Bridged23; MFG Part Num SKIP
Q501, Q504, Q711: 2N3904; TO-92L_Inline_Wide; MFG Part Num 2N3904BU; Mouser 512-2N3904BU
Q502, Q503: 2N3906; TO-92L_Inline_Wide; MFG Part Num 2N3906BU; Mouser 512-2N3906BU
R109: 68; R_Axial_DIN0309_L9.0mm_D3.2mm_P12.70mm_Horizontal; MFG Part Num MFR-25FBF52-68R; Mouser 603-MFR-25FBF52-68R
R501, R504, R505, R506, R509, R510: 10K; R_Axial_DIN0309_L9.0mm_D3.2mm_P12.70mm_Horizontal; MFG Part Num MFR-25FBF52-10K; Mouser 603-MFR-25FBF52-10K
R502: 2.7k; R_Axial_DIN0309_L9.0mm_D3.2mm_P12.70mm_Horizontal; MFG Part Num MFR-25FBF52-2K7; Mouser 603-MFR-25FBF52-2K7
R503, R508: 4.7k; R_Axial_DIN0309_L9.0mm_D3.2mm_P12.70mm_Horizontal; MFG Part Num MFR-25FBF52-4K7; Mouser 603-MFR-25FBF52-4K7
R507: 100; R_Axial_DIN0309_L9.0mm_D3.2mm_P12.70mm_Horizontal; MFG Part Num MFR-25FBF52-100R; Mouser 603-MFR-25FBF52-100R
R711: 1M; R_Axial_DIN0309_L9.0mm_D3.2mm_P12.70mm_Horizontal; MFG Part Num MFR-25FBF52-1M; Mouser 603-MFR-25FBF52-1M
R712: 47k; R_Axial_DIN0309_L9.0mm_D3.2mm_P12.70mm_Horizontal; MFG Part Num MFR-25FBF52-47K; Mouser 603-MFR-25FBF52-47K
R713: 1k; R_Axial_DIN0309_L9.0mm_D3.2mm_P12.70mm_Horizontal; MFG Part Num MFR-25FBF52-1K; Mouser 603-MFR-25FBF52-1K
RP501: 10K; R_Array_SIP10; MFG Part Num 4610X-101-103LF; Mouser 652-4610X-1LF-10K
U7, U8: VIA_8520; DIP-40_W15.24mm_Socket_LongPads; MFG Part Num 4840-6000-CP; Mouser 517-4840-6000-CP
U38: MC1488; DIP-14_W7.62mm_LongPads; MFG Part Num SN75C188N; Mouser 595-SN75C188N
U39: MC1489; DIP-14_W7.62mm_LongPads; MFG Part Num SN75C189N; Mouser 595-SN75C189N
U42: NE555; DIP-8_W7.62mm_LongPads; MFG Part Num SA555P; Mouser 595-SA555P

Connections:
+12V: E502.1, U38.14 (VCC); also elsewhere on the board
-12V: E503.1, U38.1 (VEE); also elsewhere on the board
/Parallel & Serial/+v: CN6.9, E502.3
/Parallel & Serial/-v: CN6.10, E503.3
/Parallel & Serial/cd: CN6.8, E537.3
/Parallel & Serial/clock: CN13.1, E632.1
/Parallel & Serial/cts: CN6.5, E535.3
/Parallel & Serial/data: CN13.2, E631.1
/Parallel & Serial/dsr: CN6.6, E536.3
/Parallel & Serial/dtr: CN6.20, E531.3
/Parallel & Serial/inuse: CN13.8, Q503.3 (C)
/Parallel & Serial/pp0: E512.1, U7.10 (PB0)
/Parallel & Serial/pp1: E513.1, U7.11 (PB1)
/Parallel & Serial/pp2: E514.1, U7.12 (PB2)
/Parallel & Serial/pp3: E515.1, U7.13 (PB3)
/Parallel & Serial/pp4: E516.1, U7.14 (PB4)
/Parallel & Serial/pp5: E517.1, U7.15 (PB5)
/Parallel & Serial/pp6: E518.1, U7.16 (PB6)
/Parallel & Serial/pp7: E519.1, U7.17 (PB7)
/Parallel & Serial/rts: CN6.4, E533.3
/Parallel & Serial/rxd: CN6.3, E534.3
/Parallel & Serial/sel0_out: J90.1, J90.2, U8.13 (PB3)
/Parallel & Serial/sel1_out: J90.5, J90.6, U8.14 (PB4)
/Parallel & Serial/status: CN13.7, Q502.3 (C), R507.1
/Parallel & Serial/txd: CN6.2, E532.3
/Parallel & Serial/~auto: CN7.14, E501.3
/Parallel & Serial/~init: CN7.16, E520.3
A8: U7.38 (RS0), U8.38 (RS0); also elsewhere on the board
A9: U7.37 (RS1), U8.37 (RS1); also elsewhere on the board
A10: U7.36 (RS2), U8.36 (RS2); also elsewhere on the board
A11: U7.35 (RS3), U8.35 (RS3); also elsewhere on the board
AUDIN: C501.1; also elsewhere on the board
AUDOUT: C502.2; also elsewhere on the board
D0: U7.33 (D0); also elsewhere on the board
D1: U7.32 (D1); also elsewhere on the board
D2: U7.31 (D2); also elsewhere on the board
D3: U7.30 (D3); also elsewhere on the board
D4: U7.29 (D4); also elsewhere on the board
D5: U7.28 (D5); also elsewhere on the board
D6: U7.27 (D6); also elsewhere on the board
D7: U7.26 (D7); also elsewhere on the board
D8: U8.33 (D0); also elsewhere on the board
D9: U8.32 (D1); also elsewhere on the board
D10: U8.31 (D2); also elsewhere on the board
D11: U8.30 (D3); also elsewhere on the board
D12: U8.29 (D4); also elsewhere on the board
D13: U8.28 (D5); also elsewhere on the board
D14: U8.27 (D6); also elsewhere on the board
D15: U8.26 (D7); also elsewhere on the board
DIR: U8.11 (PB1); also elsewhere on the board
E: R109.2; also elsewhere on the board
GND: C7.2, C8.2, C39.2, C42.2, C711.2, C712.2, C713.2, CN6.0 (PAD), CN6.7, CN7.0 (PAD), CN7.17, CN7.18, CN7.19, CN7.20, CN7.21, CN7.22, CN7.23, CN7.24, CN7.25, CN13.6, D501.2 (A), E501.2, E502.2, E503.2, E511.2, E512.2, E513.2, E514.2, E515.2, E516.2, E517.2, E518.2, E519.2, E520.2, E521.2, E522.2, E523.2, E524.2, E531.2, E532.2, E533.2, E534.2, E535.2, E536.2, E537.2, E538.2, E631.2, E632.2, Q501.1 (E), Q504.1 (E), Q711.1 (E), R501.1, R509.2, U7.1 (GND), U8.1 (GND), U38.7 (GND), U39.7 (GND), U42.1 (GND); also elsewhere on the board
unnamed: C502.1, CN6.11
unnamed: C501.2, CN6.18
unnamed: CN6.22, E538.3
unnamed: CN7.1, E511.3
unnamed: CN7.2, E512.3
unnamed: CN7.3, E513.3
unnamed: CN7.4, E514.3
unnamed: CN7.5, E515.3
unnamed: CN7.6, E516.3
unnamed: CN7.7, E517.3
unnamed: CN7.8, E518.3
unnamed: CN7.9, E519.3
unnamed: CN7.10, E521.3
unnamed: CN7.11, E522.3
unnamed: CN7.12, E523.3
unnamed: CN7.13, E524.3
unnamed: D501.1 (K), Q501.2 (B), R501.2, R502.2
unnamed: E538.1, R502.1
unnamed: J99.1, Q504.3 (C), R508.2
unnamed: J99.2, R510.2
unnamed: JP1.1 (A), Q711.3 (C)
unnamed: JP7B1.2 (C), U7.19 (TICK)
unnamed: E524.1, Q501.3 (C), RP501.4 (R3), U8.4 (PA2)
unnamed: Q502.2 (B), R503.1
unnamed: Q504.2 (B), R509.1, R510.1
unnamed: Q711.2 (B), R713.1
unnamed: E521.1, RP501.6 (R5), U7.24 (~F)
unnamed: E511.1, RP501.10 (R9), U7.18 (~PC)
unnamed: R109.1, U7.25 (E), U8.25 (E)
unnamed: E523.1, U8.3 (PA1), U8.40 (C)
unnamed: E522.1, U8.2 (PA0), U8.39 (S)
unnamed: U8.8 (PA6), U38.4 (IN1_B)
unnamed: E533.1, U38.6 (OUT_B)
unnamed: E532.1, U38.8 (OUT_C)
unnamed: U8.9 (PA7), U38.12 (IN2_D)
unnamed: E531.1, U38.11 (OUT_D)
unnamed: E534.1, U39.1 (IN_A)
unnamed: E535.1, U39.4 (IN_B)
unnamed: U8.6 (PA4), U39.6 (OUT_B)
unnamed: E536.1, U39.10 (IN_C)
unnamed: U8.5 (PA3), U39.8 (OUT_C)
unnamed: E537.1, U39.13 (IN_D)
unnamed: U8.7 (PA5), U39.11 (OUT_D)
unnamed: C713.1, U42.5 (CV)
unnamed: C712.1, R712.1, U42.6 (THR), U42.7 (DIS)
unnamed: R713.2, U42.3 (Q)
unnamed: C711.1, R711.1, U42.2 (TR)
OVL: U7.2 (PA0); also elsewhere on the board
R~W: U7.22 (~W), U8.22 (~W); also elsewhere on the board
VCC: C7.1, C8.1, C39.1, C42.1, CN13.4, E501.1, Q502.1 (E), Q503.1 (E), R505.2, R506.2, R507.2, R711.2, R712.2, RP501.1 (common), U7.20 (VCC), U8.20 (VCC), U38.5 (IN2_B), U38.10 (IN1_C), U38.13 (IN1_D), U39.14 (VCC), U42.4 (R), U42.8 (VCC); also elsewhere on the board
~CHNG: U7.4 (PA2); also elsewhere on the board
~DRVLED: Q503.2 (B), R504.1, R508.1
~EVEN_CIA: U8.23 (~CS); also elsewhere on the board
~EXTICK: JP7B1.1 (A), RP501.9 (R8); also elsewhere on the board
~FIRE0: U7.8 (PA6); also elsewhere on the board
~FIRE1: U7.9 (PA7); also elsewhere on the board
~HSYNC: U8.19 (TICK); also elsewhere on the board
~INDEX: RP501.7 (R6), U8.24 (~F); also elsewhere on the board
~INT2: U7.21 (~INT); also elsewhere on the board
~INT6: U8.21 (~INT); also elsewhere on the board
~IORESET: E520.1; also elsewhere on the board
~KBCLOCK: E632.3, RP501.2 (R1), U7.40 (C)
~KBDATA: E631.3, RP501.3 (R2), U7.39 (S)
~KBRESET: CN13.3, JP1.2 (B), RP501.5 (R4); also elsewhere on the board
~LED: R503.2, R505.1, U7.3 (PA1); also elsewhere on the board
~MTR0: R504.2, R506.1; also elsewhere on the board
~MTR: U8.17 (PB7); also elsewhere on the board
~ODD_CIA: U7.23 (~CS); also elsewhere on the board
~RDY: U7.7 (PA5); also elsewhere on the board
~RESET: U7.34 (~RESET), U8.34 (~RESET); also elsewhere on the board
~RXD: U39.3 (OUT_A); also elsewhere on the board
~SEL0: J90.3; also elsewhere on the board
~SEL1: J90.4; also elsewhere on the board
~SEL2: U8.15 (PB5); also elsewhere on the board
~SEL3: U8.16 (PB6); also elsewhere on the board
~SIDE: U8.12 (PB2); also elsewhere on the board
~STEP: U8.10 (PB0); also elsewhere on the board
~TRK0: U7.6 (PA4); also elsewhere on the board
~TXD: U38.9 (IN2_C); also elsewhere on the board
~VSYNC: JP7B1.3 (B); also elsewhere on the board
~WPROT: U7.5 (PA3); also elsewhere on the board

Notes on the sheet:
rxc
ADDITIONAL CIRCUITRY TO BLINK THE FLOPPY LED ON HARD DISK ACTIVITY. PIN 1 IS A 5V COMPATIBLE ACTIVE LOW INPUT. PIN 2 IS A 3.3V/5V COMPATIBLE ACTIVE HIGH INPUT. EXAMPLE USAGES: CONNECT J99 PIN1 TO PIN 39 OF CF ADAPTERS OR ALTERNATIVELY CONNECT J99 PIN 2 TO J2 PIN 1 OF THE A500-SD-PLUS CONTROLLER
Simple implementation of a floppy drive switcher that will allow using the first external drive as DF0:. The internal drive will not be accessible in this case.
~{EXTICK} is not connected here in original schematics, but it is on the actual board.
scts
srts
stxd
KEYBOARD CONNECTOR
POWER
clk
srxd
scd
POWER-UP RESET
txc
THIS CONNECTION IS MISSING ON THE ORIGINAL SCHEMATICS BUT PRESENT ON ACTUAL BOARDS! (THANKS LIV2)
sqd
RS232 DECOUPLING
PARALLEL PORT
~{err}
RS232

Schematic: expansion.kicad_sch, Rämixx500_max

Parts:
E702, E703, E704: 10n; EMI_Filter_Short; MFG Part Num DSS1NB32A103Q91A; Mouser 81-DSS1NB32A103Q91A
P1: EXPANSION BUS; A500_SIDE_SLOT; MFG Part Num SKIP

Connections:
7MHZ: P1.7 (7MHZ); also elsewhere on the board
+12V: E704.1; also elsewhere on the board
-12V: E703.1; also elsewhere on the board
A1: P1.29 (A1); also elsewhere on the board
A2: P1.27 (A2); also elsewhere on the board
A3: P1.26 (A3); also elsewhere on the board
A4: P1.24 (A4); also elsewhere on the board
A5: P1.21 (A5); also elsewhere on the board
A6: P1.23 (A6); also elsewhere on the board
A7: P1.28 (A7); also elsewhere on the board
A8: P1.30 (A8); also elsewhere on the board
A9: P1.32 (A9); also elsewhere on the board
A10: P1.34 (A10); also elsewhere on the board
A11: P1.36 (A11); also elsewhere on the board
A12: P1.38 (A12); also elsewhere on the board
A13: P1.39 (A13); also elsewhere on the board
A14: P1.41 (A14); also elsewhere on the board
A15: P1.43 (A15); also elsewhere on the board
A16: P1.45 (A16); also elsewhere on the board
A17: P1.47 (A17); also elsewhere on the board
A18: P1.52 (A18); also elsewhere on the board
A19: P1.54 (A19); also elsewhere on the board
A20: P1.56 (A20); also elsewhere on the board
A21: P1.58 (A21); also elsewhere on the board
A22: P1.57 (A22); also elsewhere on the board
A23: P1.59 (A23); also elsewhere on the board
CDAC: P1.15 (~CDAC); also elsewhere on the board
D0: P1.75 (D0); also elsewhere on the board
D1: P1.77 (D1); also elsewhere on the board
D2: P1.79 (D2); also elsewhere on the board
D3: P1.81 (D3); also elsewhere on the board
D4: P1.83 (D4); also elsewhere on the board
D5: P1.86 (D5); also elsewhere on the board
D6: P1.84 (D6); also elsewhere on the board
D7: P1.82 (D7); also elsewhere on the board
D8: P1.80 (D8); also elsewhere on the board
D9: P1.78 (D9); also elsewhere on the board
D10: P1.76 (D10); also elsewhere on the board
D11: P1.71 (D11); also elsewhere on the board
D12: P1.69 (D12); also elsewhere on the board
D13: P1.67 (D13); also elsewhere on the board
D14: P1.65 (D14); also elsewhere on the board
D15: P1.63 (D15); also elsewhere on the board
E: P1.50 (E); also elsewhere on the board
FC0: P1.31 (FC0); also elsewhere on the board
FC1: P1.33 (FC1); also elsewhere on the board
FC2: P1.35 (FC2); also elsewhere on the board
GND: E702.2, E703.2, E704.2, P1.1 (GND), P1.2 (GND), P1.3 (GND), P1.4 (GND), P1.12 (~CONFIG), P1.13 (GND), P1.25 (GND), P1.37 (GND), P1.49 (GND), P1.61 (GND), P1.73 (GND), P1.85 (GND); also elsewhere on the board
unnamed: E702.3, P1.5 (VCC), P1.6 (VCC)
unnamed: E704.3, P1.10 (+12V)
unnamed: E703.3, P1.8 (-12V)
R~W: P1.68 (R~W); also elsewhere on the board
VCC: E702.1; also elsewhere on the board
XRDY: P1.18 (XRDY); also elsewhere on the board
~AS: P1.74 (~AS); also elsewhere on the board
~BEER: P1.46 (~BERR); also elsewhere on the board
~BGACK: P1.62 (~BGACK); also elsewhere on the board
~BG: P1.64 (~BG); also elsewhere on the board
~BR: P1.60 (~BR); also elsewhere on the board
~CCKQ: P1.14 (~CCKQ); also elsewhere on the board
~CCK: P1.16 (~CCK); also elsewhere on the board
~DTACK: P1.66 (~DTACK); also elsewhere on the board
~HLT: P1.55 (~HALT); also elsewhere on the board
~INT2: P1.19 (~INT2); also elsewhere on the board
~INT6: P1.22 (~INT6); also elsewhere on the board
~IPL0: P1.40 (~IPL0); also elsewhere on the board
~IPL1: P1.42 (~IPL1); also elsewhere on the board
~IPL2: P1.44 (~IPL2); also elsewhere on the board
~LDS: P1.70 (~LDS); also elsewhere on the board
~OVR: P1.17 (~OVR); also elsewhere on the board
~RST: P1.53 (~RESET); also elsewhere on the board
~UDS: P1.72 (~UDS); also elsewhere on the board
~VMA: P1.51 (~VMA); also elsewhere on the board
~VPA: P1.48 (~VPA); also elsewhere on the board

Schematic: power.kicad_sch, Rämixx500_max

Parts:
C1, C2, C5, C11, C13, C14, C804: 330n; C_Axial_L6.3mm_D2.5mm_P10.16mm; MFG Part Num C440C334K5R5TA7200; Mouser 80-C440C334K5R-TR
C10, C12, C32, C34, C35, C36, C37, C701, C800, C801, C802, C803: 10n; C_Axial_L6.3mm_D2.5mm_P10.16mm; MFG Part Num C410C103K1R5TA; Mouser 80-C410C103K1R
C811, C812, C813, C814, C815, C816: 100u; CP_Radial_D8.0mm_P5.00mm; MFG Part Num ECA-1VM101B; Mouser 667-ECA-1VM101B
C821, C822: 47u; CP_Radial_D8.0mm_P5.00mm; MFG Part Num ECA-1VM470B; Mouser 667-ECA-1VM470B
CN8: POWER; DS215+DIN8_COMBO; MFG Part Num 252167-01
E101, E110: 10n; EMI_Filter_Short; MFG Part Num DSS1NB32A103Q91A; Mouser 81-DSS1NB32A103Q91A
LF1: L; LineFilter; not fitted
LF99: CM4545Z131B-10; MFG Part Num CM4545Z131B-10; Mouser 875-CM4545Z131B-10
MT1, MT2, MT4, MT5, MT6, MT7: MountingHole_Pad; MountingHole_4mm_Pad; MFG Part Num SKIP
U1: 68000D; DIP-64_W22.86mm_Socket_LongPads; MFG Part Num 110-93-964-41-001000; Mouser 575-193964
U2: FAT_AGNUS_8375; PLCC-84_THT-Socket; MFG Part Num 940-44-084-24-000000; Mouser 575-948424
U5: GARY_5719; DIP-48_W15.24mm_Socket_LongPads; MFG Part Num 4848-6000-CP; Mouser 517-4848-6000-CP
U10, U12: 74LS244; DIP-20_W7.62mm_LongPads; MFG Part Num SN74LS244N; Mouser 595-SN74LS244N
U11, U13: 74LS373; DIP-20_W7.62mm_LongPads; MFG Part Num SN74LS373N; Mouser 595-SN74LS373N
U32: 74F139; DIP-16_W7.62mm_LongPads; MFG Part Num CD74ACT139E; Mouser 595-CD74ACT139E
U34, U35: 74F244; DIP-20_W7.62mm_LongPads; MFG Part Num SN74F244N; Mouser 595-SN74F244N
U36: 74LS05; DIP-14_W7.62mm_LongPads; MFG Part Num SN74LS05N; Mouser 595-SN74LS05N
U37: 74LS32; DIP-14_W7.62mm_LongPads; MFG Part Num SN74LS32N; Mouser 595-SN74LS32N
X1: XTAL; Oscillator_DIP-14

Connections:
+12V: C802.1, C821.1, LF1.5, LF99.5; also elsewhere on the board
-12V: C803.2, C822.2, LF1.6, LF99.6; also elsewhere on the board
GND: C1.2, C2.2, C5.2, C10.2, C11.2, C12.2, C13.2, C14.2, C32.2, C34.2, C35.2, C36.2, C37.2, C701.2, C801.2, C802.2, C803.1, C804.2, C811.2, C812.2, C813.2, C814.2, C815.2, C816.2, C821.2, C822.1, CN8.2 (SH1), CN8.6 (SH2), E101.2, E110.2, LF1.8, LF99.8, MT1.1, MT2.1, MT4.1, MT5.1, MT6.1, MT7.1, U1.16 (GND), U1.53 (GND), U2.41 (GND), U2.58 (GND), U2.82 (GND), U5.1 (GND), U5.24 (GND), U5.40 (GND), U10.10 (GND), U11.10 (GND), U12.10 (GND), U13.10 (GND), U32.8 (GND), U34.10 (GND), U35.10 (GND), U36.7 (GND), U37.7 (GND), X1.1 (~EN), X1.7 (GND); also elsewhere on the board
unnamed: C800.2, CN8.1 (+5V), LF1.2, LF99.2
unnamed: CN8.3 (+12V), LF1.4, LF99.4
unnamed: CN8.5 (-12V), LF1.3, LF99.3
unnamed: C800.1, CN8.4 (GND), LF1.1, LF99.1
unnamed: C2.1, E101.3, U2.15 (VCC)
unnamed: C701.1, E110.3, X1.14 (VDD)
VCC: C1.1, C5.1, C10.1, C11.1, C12.1, C13.1, C14.1, C32.1, C34.1, C35.1, C36.1, C37.1, C801.1, C804.1, C811.1, C812.1, C813.1, C814.1, C815.1, C816.1, E101.1, E110.1, LF1.7, LF99.7, U1.14 (VCC), U1.49 (VCC), U5.6 (VCC), U5.17 (VCC), U5.48 (VCC), U10.20 (VCC), U11.20 (VCC), U12.20 (VCC), U13.20 (VCC), U32.16 (VCC), U34.20 (VCC), U35.20 (VCC), U36.14 (VCC), U37.14 (VCC); also elsewhere on the board
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

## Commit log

2026-02-22 schematic imported into KiCad 9 and fixed annotation errors and more due to import.
    [Raemixx500.kicad_sch, Raemixx500.sch, audio.kicad_sch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]
2026-02-22 PCB file converted to KiCad 9.
2026-02-23 cleaned up side connector footprint to get rid of DRC errors
    [expansion.kicad_sch]
2026-02-24 pin 1 and 3 were swapped
2026-02-25 fixed annular ring DRC on SUB-D and at the same time made all SUB-D footprints the same
2026-02-25 updated changed footprints
2026-02-28 fixed some schematic parity DRC warnings.
2026-02-28 belongs to previous commit, fixed schematic parity DRC errors
    [cias.kicad_sch]
2026-02-28 Added footprint for 72pin SIMM
    [c-5822134-3-b-3d.stp]
2026-03-05 added separate power unit for SIMM
2026-03-10 added 3D model for SIMM module
    [SIMM_Richard_Barber_GrabCAD.STEP]
2026-03-13 DRAM chips replaced with SIMM module
    Added logic to decode 2MB chip + 1.5MB slow
    Rewired trapdoor slot
    [Raemixx500.kicad_sch, audio.kicad_sch, cias.kicad_sch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]
2026-03-14 optimized timing
    removed CCK from RAM buffers to ease routing
    [power.kicad_sch, ram.kicad_sch, trapdoor.kicad_sch]
2026-03-15 removed JP2
    some more small fixes
    schematic is now more or less done I think
    [cpu.kicad_sch, power.kicad_sch, ram.kicad_sch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]
2026-03-18 routing SIMM
    work in progress
    [Raemixx500.kicad_pcb, ram.kicad_sch, terminators.kicad_sch]
2026-03-21 changed wiring of pullups, simplified SIMM parity pullups
    Routed more nets. Slowly getting there. WIP
    [Raemixx500.kicad_pcb, ram.kicad_sch, terminators.kicad_sch]
2026-03-22 More work done, routing of SIMM module datapath almost done
    [Raemixx500.kicad_pcb, bom.csv, designators.csv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]
2026-03-25 Completed routing, no DRC errors (but still a lot of warnings)
    TODO: thoroughly review all small schematic changes
    [Raemixx500.kicad_pcb, Raemixx500.kicad_sch, audio.kicad_sch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]
2026-03-26 fixed bug in CAS multiplexer
    added logo
    [Raemixx500.kicad_pcb, ram.kicad_sch]
2026-03-26 added teardrops
    [Raemixx500.kicad_pcb]
2026-03-28 removed some unnecessary copper zones
    improved grounding around SIMM a bit
    [Raemixx500.kicad_pcb]
2026-04-01 small optimizations
    [Raemixx500.kicad_pcb]
2026-04-01 Improved HDD LED circuitry so that positive drive LEDs are also supported
    More routing improvements
    [Raemixx500.kicad_pcb, Raemixx500.kicad_sch, audio.kicad_sch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]
2026-04-06 - some IC are not socketed anymore to fit under shield
    - updated logo
    - silkscreen cleanup
    - added pin1 indicator to solder jumpers
    [Raemixx500.kicad_pcb, Raemixx500.kicad_sch, power.kicad_sch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]
2026-04-08 removed ESD diodes
    [Raemixx500.kicad_pcb, audio.kicad_sch]
2026-04-09 Fixed some very nasty shorts that happened many commits ago when the design was imported into KiCad9.
    [Raemixx500.kicad_pcb, audio.kicad_sch]
2026-04-09 removed some via's that I put to connect ground traces together.
    Now that the shorted nets have been fixed, these traces are no longer ground....
    [Raemixx500.kicad_pcb]
2026-04-09 Added back ESD diodes very close to sensitive pins only for more effective protection
    Made teardrops as small as possible
    [Raemixx500.kicad_pcb, Raemixx500.kicad_sch, audio.kicad_sch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]
2026-04-10 added silkscreen on top for ESD diodes on bottom
    added special symbol for keyboard header to get rid of schematic parity error
    [Raemixx500.kicad_pcb, cias.kicad_sch]
2026-04-11 Started cleaning up BOM
    [Raemixx500.kicad_sch, audio.kicad_sch, cias.kicad_sch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]
2026-04-12 Working on BOM
    [Raemixx500.kicad_sch, audio.kicad_sch, cias.kicad_sch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]
2026-04-14 more work on BOM done
    [audio.kicad_sch, cias.kicad_sch, clockdist.kicad_sch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]
2026-04-15 More BOM work
    I am marking optional components as DNP to get some overview
    [audio.kicad_sch, cias.kicad_sch, clockdist.kicad_sch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]
2026-04-19 BOM updates
    [audio.kicad_sch, cias.kicad_sch, clockdist.kicad_sch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]
2026-04-19 BOM work done
    [cias.kicad_sch, rom.kicad_sch, rtc.kicad_sch]
2026-04-19 even more BOM work
    [clockdist.kicad_sch, cpu.kicad_sch, power.kicad_sch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]
2026-04-19 added mouser part numbers
    [clockdist.kicad_sch, cpu.kicad_sch, power.kicad_sch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]
2026-04-25 replaced commodore hybrid with OpenAmigaVideoHybrid
    decided to place address pullups for better EPROM capability
    [Raemixx500.kicad_pcb, SIMM_Richard_Barber_GrabCAD.STEP, audio.kicad_sch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]
2026-04-26 added pin 1 indications like on originnal board
    changed floppy connector to non-shrouded version
    [Raemixx500.kicad_pcb, floppy.kicad_sch]
2026-04-26 more silkscreen work
    removed sockets for standard IC's
    [Raemixx500.kicad_pcb, Raemixx500.kicad_sch, audio.kicad_sch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]
2026-04-26 even more silkscreen refinements
    [Raemixx500.kicad_pcb]
2026-04-26 more refinements
    [Raemixx500.kicad_pcb]
2026-04-26 made one trace better looking :-)
    [Raemixx500.kicad_pcb]
2026-05-19 fixed R309 wrong value
    Replaced too big 2W resistors with better fitting 1W resistors
    [audio.kicad_sch, video.kicad_sch]
2026-05-21 increased hole size of variable capacitor footprint
2026-05-30 added CAD model for MFP920 floppy eject button
    [eject_button_mfp920_A500.FCStd]
2026-05-30 Added CAD model for Sony MFP920 to Chinon button.
    The Chinon button needs some cutting away
    [eject_button_mfp920_A500.FCStd, eject_button_mfp920_to_chinon_button.FCStd]
2026-06-20 updated PCB with schematics and footprint changes
    [Raemixx500.kicad_pcb]
2026-06-20 moved floppy connector 0.3mm away from audio output connectors
    bumped version on schematics and PCB to V3.1
    [Raemixx500.kicad_pcb, Raemixx500.kicad_sch, audio.kicad_sch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]
2026-06-21 added more clearance for drive frame and PCB
    [eject_button_mfp920_A500.FCStd]
2026-06-21 slightly moved location of eject button for a better fit
    [eject_button_mfp920_A500.FCStd]
2026-06-21 updated chinon to sony eject button with latest changes
    [eject_button_mfp920_to_chinon_button.FCStd]
2026-06-21 README updated
    [Raemixx500.csv]
2026-06-23 added step files for MFP920 eject buttons
    updated README
    [eject_button_mfp920_A500.step, eject_button_mfp920_to_chinon_button.step]
2026-06-23 Added pictures of MFP920 Eject buttons.
    Updated README again.

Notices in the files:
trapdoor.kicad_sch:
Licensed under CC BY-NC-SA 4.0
